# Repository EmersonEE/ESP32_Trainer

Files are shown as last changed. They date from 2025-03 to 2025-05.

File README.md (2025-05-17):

# ESP32 Trainer
Proyecto de Electrónica Aplicada 1 - **USAC**

 





 


# 📘 Temario del Proyecto

- 🔹 [Introducción](#-introducción)
- 🔹 [ESP32 Trainer](#-esp32-trainer)
- 🔹 [ESP32 Trainer Pinout](#esp32-trainer-pinout)
- 🔹 [Materiales](#-materiales)
- 🔹 [Diseño PCB - KiCad](#-diseño-pcb---kicad)
- 🔹 [Proyectos Demostrativos](#-proyectos-demostrativos)
<!-- - 🎥 [Video de Funcionamiento](#video-de-funcionamiento) -->

---

## 🧩 Introducción

En el ámbito del diseño electrónico y el desarrollo de prototipos, existe una necesidad creciente de contar con herramientas integradas que simplifiquen el proceso de aprendizaje, experimentación y construcción de soluciones funcionales. Las placas de desarrollo convencionales suelen requerir múltiples módulos adicionales para realizar proyectos completos, lo que incrementa la complejidad, los costos y el tiempo de implementación.

Este proyecto propone el diseño y fabricación de una **placa entrenadora basada en el [ESP32-WROOM-32](https://www.espressif.com/sites/default/files/documentation/esp32-wroom-32_datasheet_en.pdf)**, orientada a estudiantes, makers y profesionales. Su objetivo es integrar en una sola plataforma los elementos esenciales para trabajar con entradas/salidas digitales y analógicas, comunicación serial, control de cargas de alto voltaje, y más.

Entre sus características destacan:

- 🔘 Botones, LEDs y potenciómetros integrados para pruebas rápidas.
- ⚡ Control de cargas de 110V/220V mediante relés.
- 🔌 Interfaces UART, I2C y SPI disponibles desde headers.
- 📦 Diseño compacto y profesional en PCB de doble capa.

Con esta solución, se busca facilitar el desarrollo de proyectos de electrónica y automatización, reduciendo la necesidad de hardware adicional y mejorando la experiencia de aprendizaje.

[🔙 Volver al Temario](#-temario-del-proyecto)

## 🔌 ESP32 Trainer

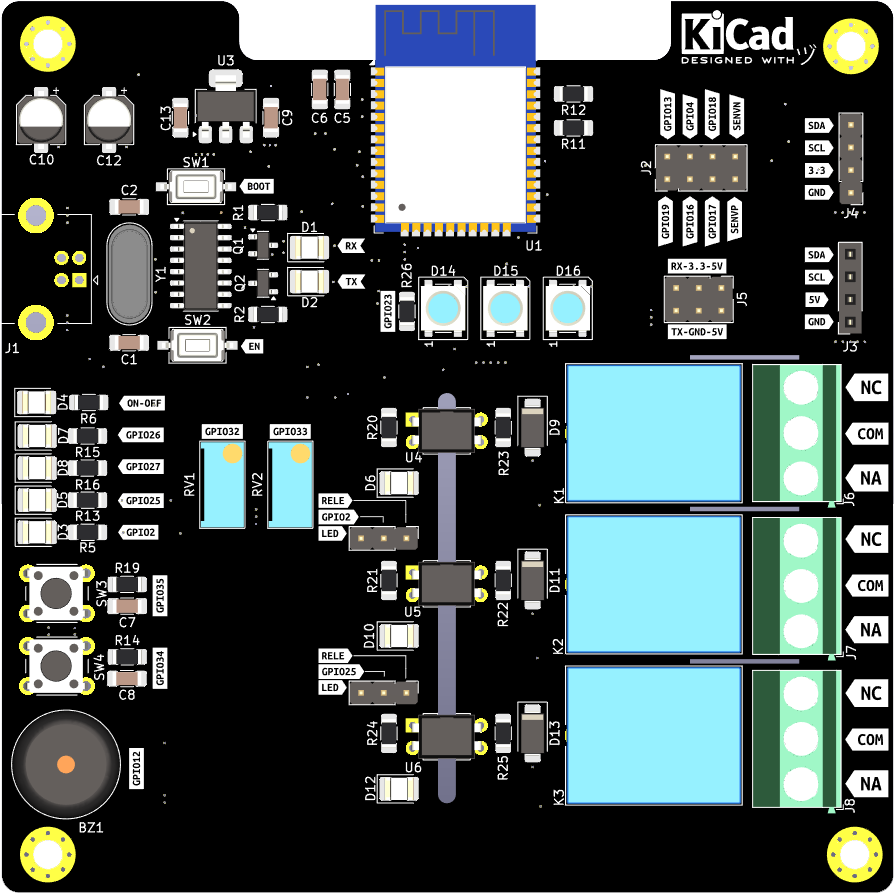
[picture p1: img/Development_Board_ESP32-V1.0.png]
ESP32 Trainer


[🔙 Volver al Temario](#-temario-del-proyecto)

## ESP32 Trainer Pinout

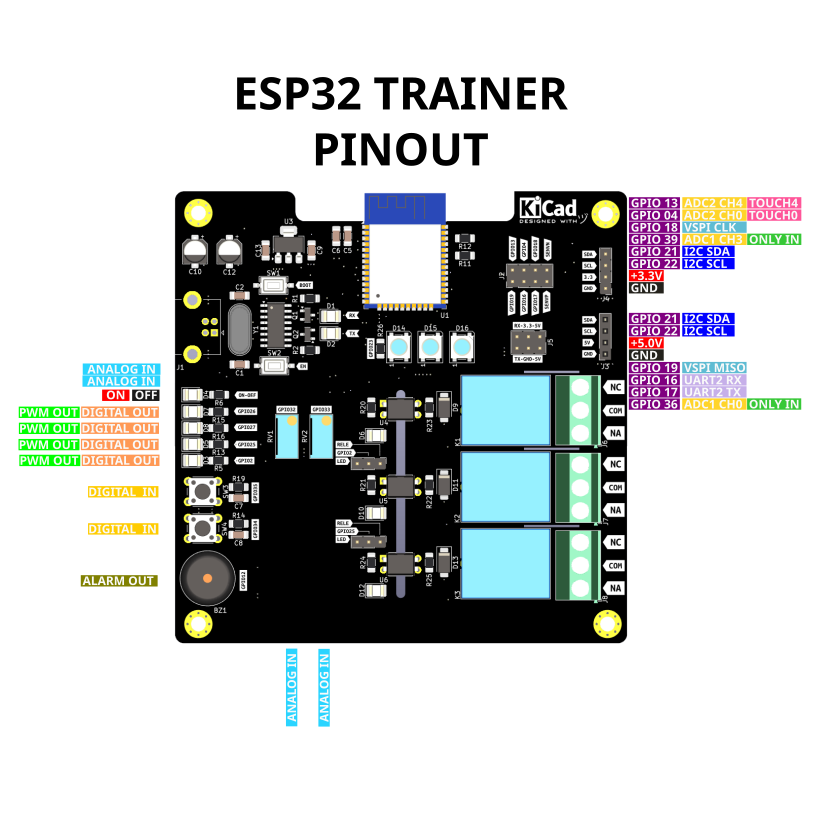
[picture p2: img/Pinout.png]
ESP32 Trainer Pinout


[Ver en PDF](pinout_esp32.pdf)

[🔙 Volver al Temario](#-temario-del-proyecto)

## 🧰 Materiales  

En esta sección se detallan todos los componentes electrónicos utilizados para el ensamblaje de la placa entrenadora basada en el ESP32-WROOM-32. La tabla incluye el identificador de cada componente, la cantidad necesaria, su valor o referencia, y el modelo de huella utilizado en el diseño PCB con KiCad.

<details><summary><b>Lista de Materiales  - BOM</b></summary>

| 🧾 Componente | 🔢 Cantidad | 💡 Valor | 📐 Huella (KiCad) |
|---|---|---|---|
| BZ1 | 1 | Buzzer | Buzzer_12x9.5RM7.6 |
| C1, C2 | 2 | 22pF | C_1206_3216Metric_Pad1.33x1.80mm_HandSolder |
| C10, C12 | 2 | 100uF | CP_Elec_5x5.4 |
| C11, C13, C5, C6, C9 | 5 | 100nF | C_1206_3216Metric_Pad1.33x1.80mm_HandSolder |
| C14–C16, C3–C4, C7–C8 | 7 | 0.1uF | C_1206_3216Metric_Pad1.33x1.80mm_HandSolder |
| D1, D10, D7  | 3 | LED Verde | LED_1210_3225Metric_Pad1.42x2.65mm_HandSolder |
| D11, D13, D9 | 3 | SS24 | D_SMA |
| D12, D3, D8  | 3 | LED Azul | LED_1210_3225Metric_Pad1.42x2.65mm_HandSolder |
| D14–D16 | 3 | WS2812B | LED_WS2812B_PLCC4_5.0x5.0mm_P3.2mm |
| D2 | 1 | LED Amarillo | LED_1210_3225Metric_Pad1.42x2.65mm_HandSolder |
| D4–D6 | 3 | LED Rojo | LED_1210_3225Metric_Pad1.42x2.65mm_HandSolder |
| J1 | 1 | USB B | USB_B_Lumberg_2411_02_Horizontal |
| J10, J9 | 2 | — | PinHeader_1x03_P2.54mm_Vertical |
| J2 | 1 | GPIO | PinHeader_2x04_P2.54mm_Vertical |
| J3 | 1 | OLED | PinSocket_1x04_P2.54mm_Vertical |
| J4 | 1 | — | PinHeader_1x04_P2.54mm_Vertical |
| J5 | 1 | — | PinHeader_2x03_P2.54mm_Vertical |
| J6–J8 | 3 | — | TerminalBlock_Phoenix_MKDS-1,5-3-5.08_1x03_P5.08mm_Horizontal |
| K1–K3 | 3 | — | Relay_SPDT_SANYOU_SRD_Series_Form_C |
| Q1–Q6 | 6 | MMBT3904 | SOT-23 |
| R1, R2, R7, R9, R11, R12 | 6 | 10K | R_1206_3216Metric_Pad1.30x1.75mm_HandSolder |
| R8, R10, R13–R16, R19–R21, R24 | 10 | 470 | R_1206_3216Metric_Pad1.30x1.75mm_HandSolder |
| R17, R22–R23, R25 | 4 | 2.2K | R_1206_3216Metric_Pad1.30x1.75mm_HandSolder |
| R18 | 1 | 4.7K | R_1206_3216Metric_Pad1.30x1.75mm_HandSolder |
| R26 | 1 | 220 | R_1206_3216Metric_Pad1.30x1.75mm_HandSolder |
| R3, R4 | 2 | 2K | R_1206_3216Metric_Pad1.30x1.75mm_HandSolder |
| R5, R6 | 2 | 1K | R_1206_3216Metric_Pad1.30x1.75mm_HandSolder |
| RV1, RV2 | 2 | 100K Pot | Potentiometer_Bourns_3296W_Vertical |
| SW1, SW2 | 2 | — | SW_Tactile_SPST_NO_Straight_CK_PTS636Sx25SMTRLFS |
| SW3, SW4 | 2 | — | SW_PUSH_6mm |
| U1 | 1 | ESP32-WROOM-32 | ESP32-WROOM-32 |
| U2 | 1 | CH340G | SOIC-16_3.9x9.9mm_P1.27mm |
| U3 | 1 | AMS1117-3.3 | SOT-223-3_TabPin2 |
| U4–U6 | 3 | PC817 | DIP-4_W7.62mm |
| Y1 | 1 | 12MHz | Crystal_HC49-4H_Vertical |
</details>

[🔙 Volver al Temario](#-temario-del-proyecto)

## 🖨️ Diseño PCB - KiCad

 [KiCad](https://www.kicad.org/) se utilizó para el diseño de la placa entrenadora basada en el ESP32-WROOM-32, permitiendo crear el esquemático del circuito, asignar huellas adecuadas a los componentes y generar el diseño del PCB en múltiples capas. Gracias a sus herramientas de visualización y comprobación de reglas, fue posible optimizar el diseño para su posterior fabricación con alta precisión.

<details><summary><b>📏 Esquemático KiCad</b></summary>

Esquemático diseñado en Kicad, se puede visualizar de forma completa en este enlace [Esquemático](Schematic.pdf)
<div align="center" >
  <p style="text-align:center;"><strong>Power Supply</strong></p>
  <p style="text-align:center;">
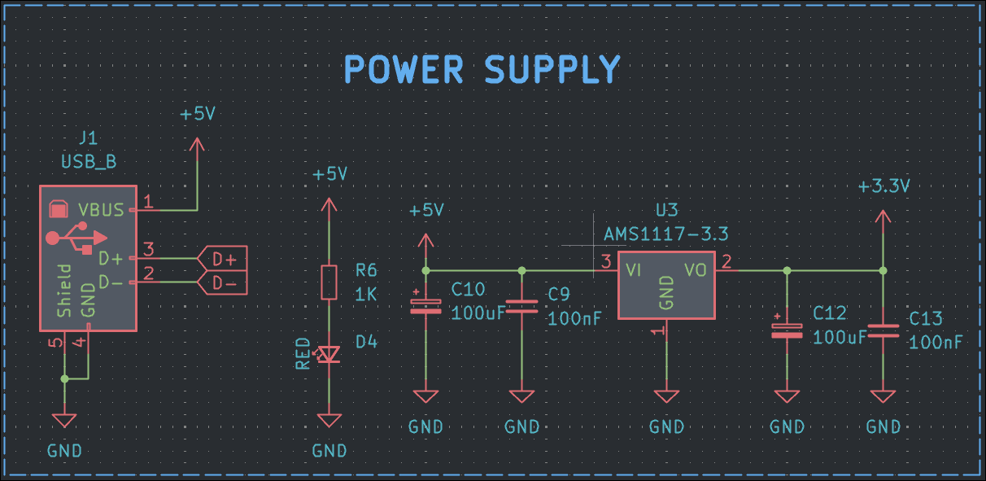
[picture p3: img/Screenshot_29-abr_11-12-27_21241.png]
Power Supply
    
  </p>
</div>

<div align="center" >
  <p style="text-align:center;"><strong>USB To TTL</strong></p>
  <p style="text-align:center;">
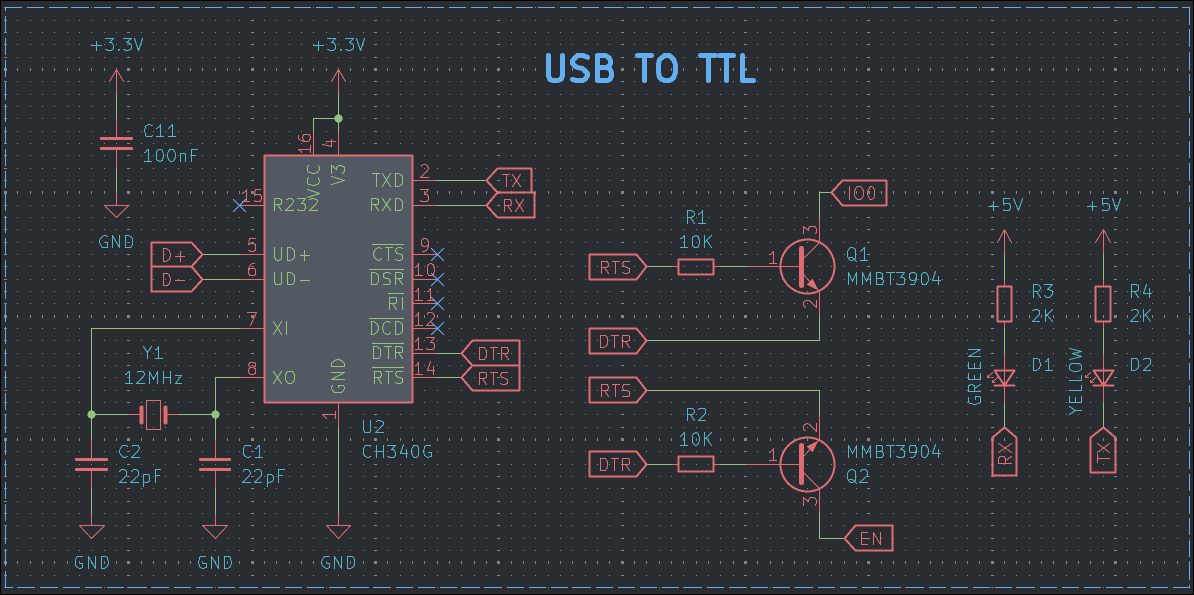
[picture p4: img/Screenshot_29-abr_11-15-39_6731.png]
USB To TTL
    
  </p>
</div>

<div align="center" >
  <p style="text-align:center;"><strong>Boot Settings</strong></p>
  <p style="text-align:center;">
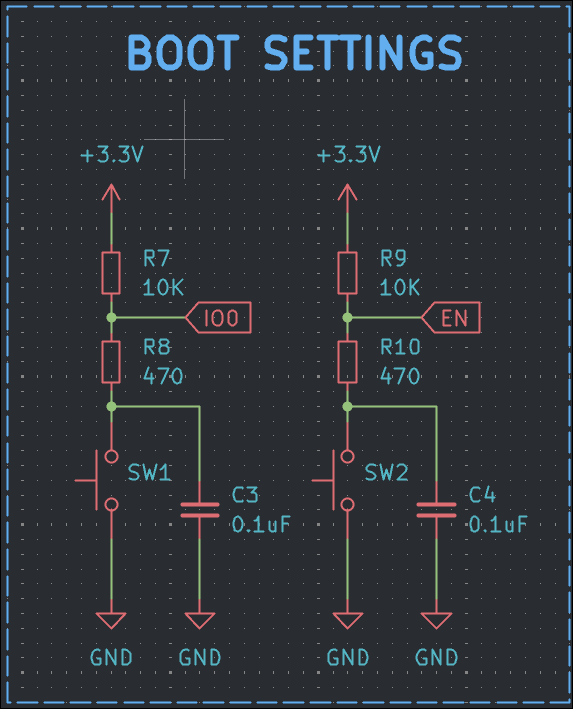
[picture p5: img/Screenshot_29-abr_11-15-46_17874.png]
Boot Settings
    
  </p>
</div>

<div align="center" >
  <p style="text-align:center;"><strong>INPUT - OUTPUT Digital</strong></p>
  <p style="text-align:center;">
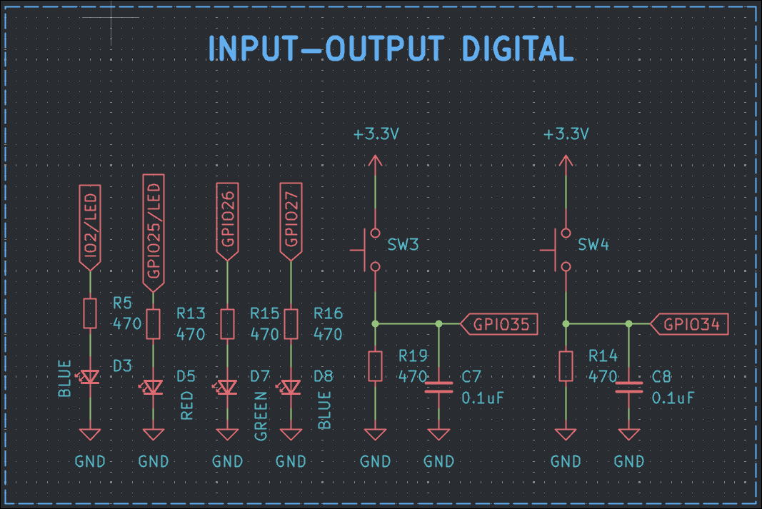
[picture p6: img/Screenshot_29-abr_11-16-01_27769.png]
INPUT - OUTPUT Digital
    
  </p>
</div>

<div align="center" >
  <p style="text-align:center;"><strong>ESP32-WROOM</strong></p>
  <p style="text-align:center;">
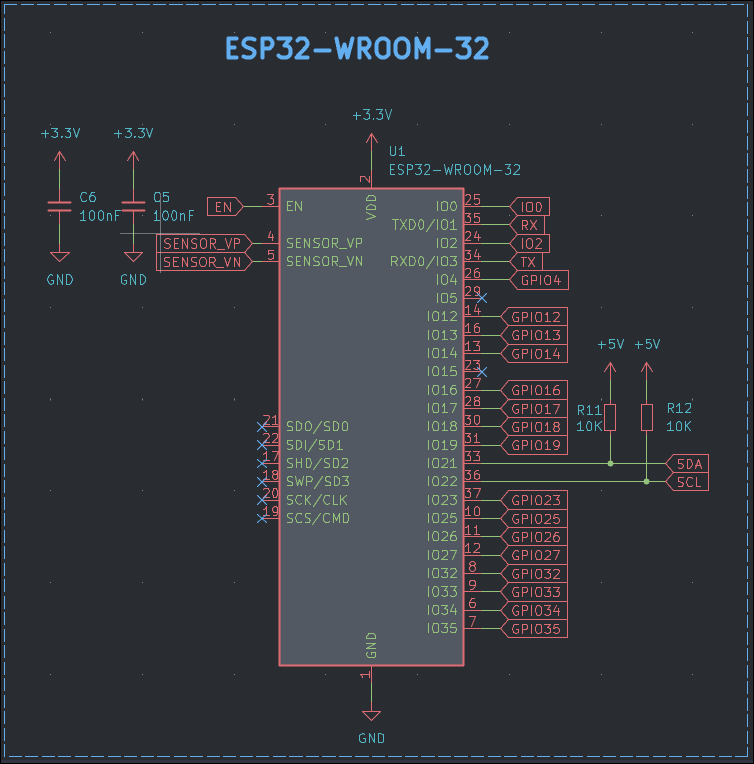
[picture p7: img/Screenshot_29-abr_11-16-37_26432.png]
ESP32-WROOM
    
  </p>
</div>

<div align="center" >
  <p style="text-align:center;"><strong>Analog INPUT</strong></p>
  <p style="text-align:center;">
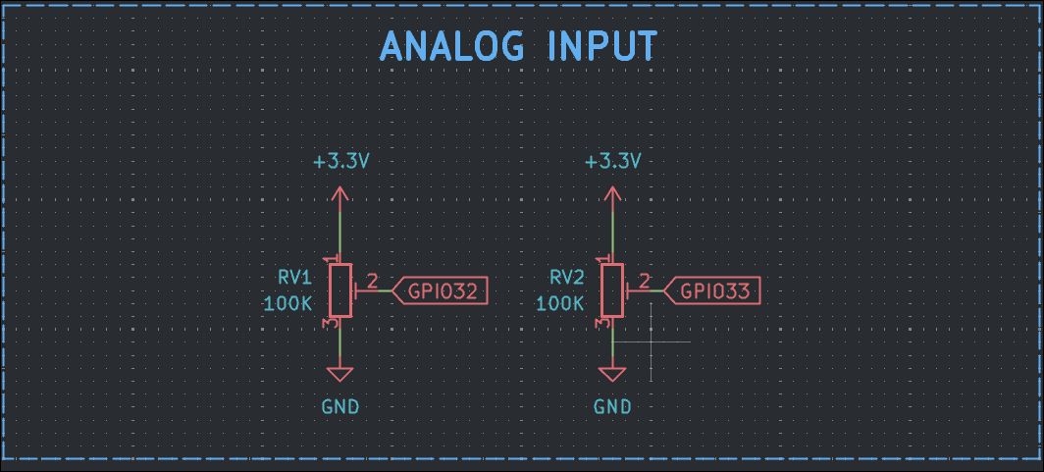
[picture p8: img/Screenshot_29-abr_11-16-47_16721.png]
Analog INPUT
    
  </p>
</div>

<div align="center" >
  <p style="text-align:center;"><strong>LED WS2812B</strong></p>
  <p style="text-align:center;">
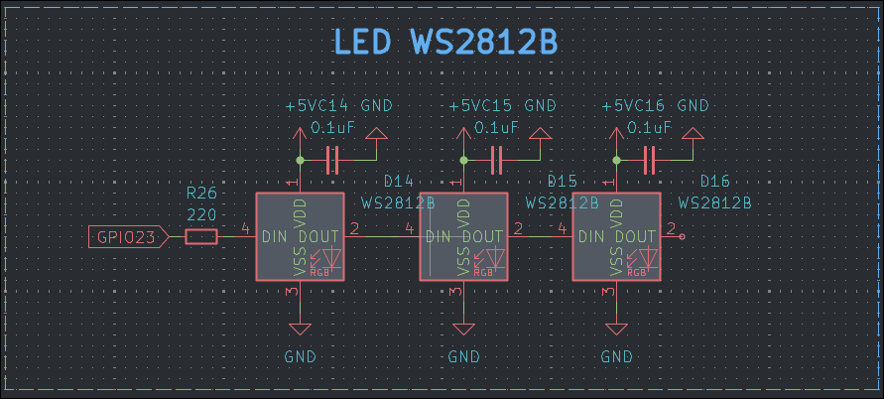
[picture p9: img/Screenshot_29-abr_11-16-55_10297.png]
LED WS2812B
    
  </p>
</div>

<div align="center" >
  <p style="text-align:center;"><strong>Buzzer</strong></p>
  <p style="text-align:center;">
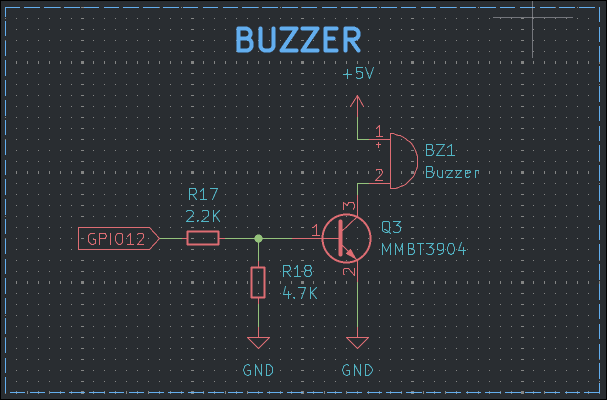
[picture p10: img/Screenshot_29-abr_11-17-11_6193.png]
Buzzer
    
  </p>
</div>

<div align="center" >
  <p style="text-align:center;"><strong>Jumper Selector</strong></p>
  <p style="text-align:center;">
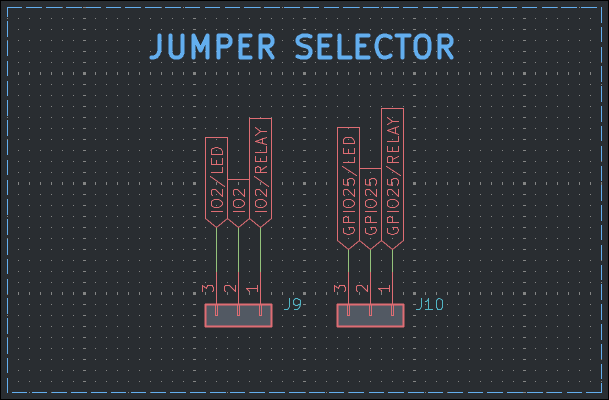
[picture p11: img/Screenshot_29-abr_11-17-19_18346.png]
Jumper Selector
    
  </p>
</div>

<div align="center" >
  <p style="text-align:center;"><strong>GPIO - UART</strong></p>
  <p style="text-align:center;">
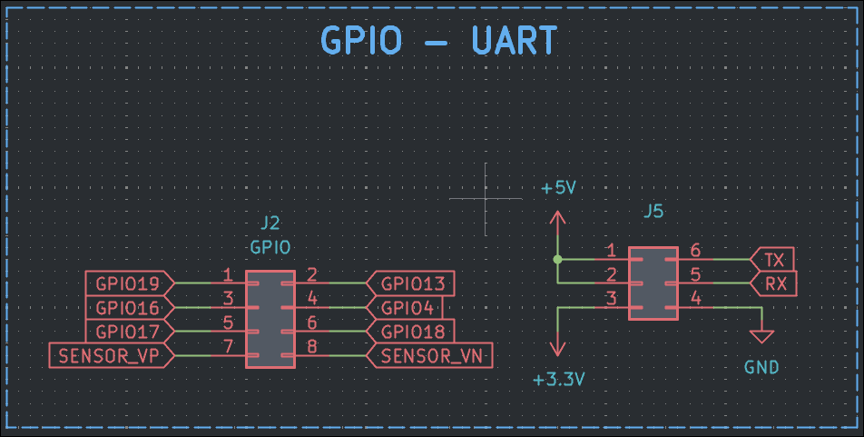
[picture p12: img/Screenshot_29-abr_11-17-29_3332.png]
GPIO - UART
    
  </p>
</div>

<div align="center" >
  <p style="text-align:center;"><strong>OLED I2C</strong></p>
  <p style="text-align:center;">
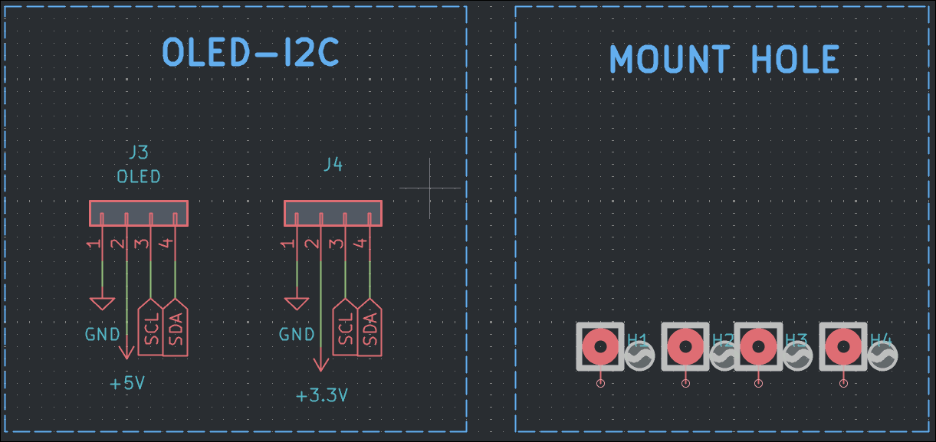
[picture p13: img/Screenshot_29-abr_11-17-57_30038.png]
    
  </p>
</div>

<div align="center" >
  <p style="text-align:center;"><strong>Rele</strong></p>
  <p style="text-align:center;">
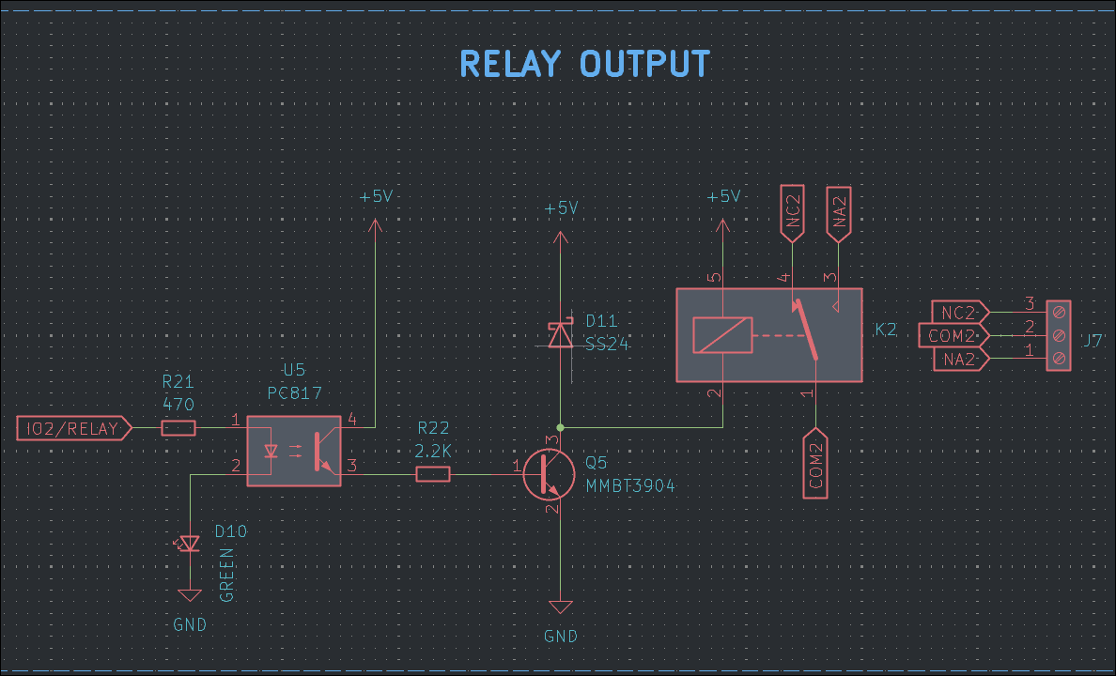
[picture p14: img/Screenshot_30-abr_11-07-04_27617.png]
    
  </p>
</div>

</details>

<details><summary><b>🔌 Diseño del PCB </b></summary>

Diseño de la PCB en dos caras, se puede descargar los archivos para su modificación o su estudio en aca [Descargar archivos del  PCB](https://github.com/EmersonEE/ESP32_Trainer/releases/tag/untagged-a26e2b24809520548798)

<div align="center" >
  <p style="text-align:center;"><strong>Diseño 3D</strong></p>
  <p style="text-align:center;">
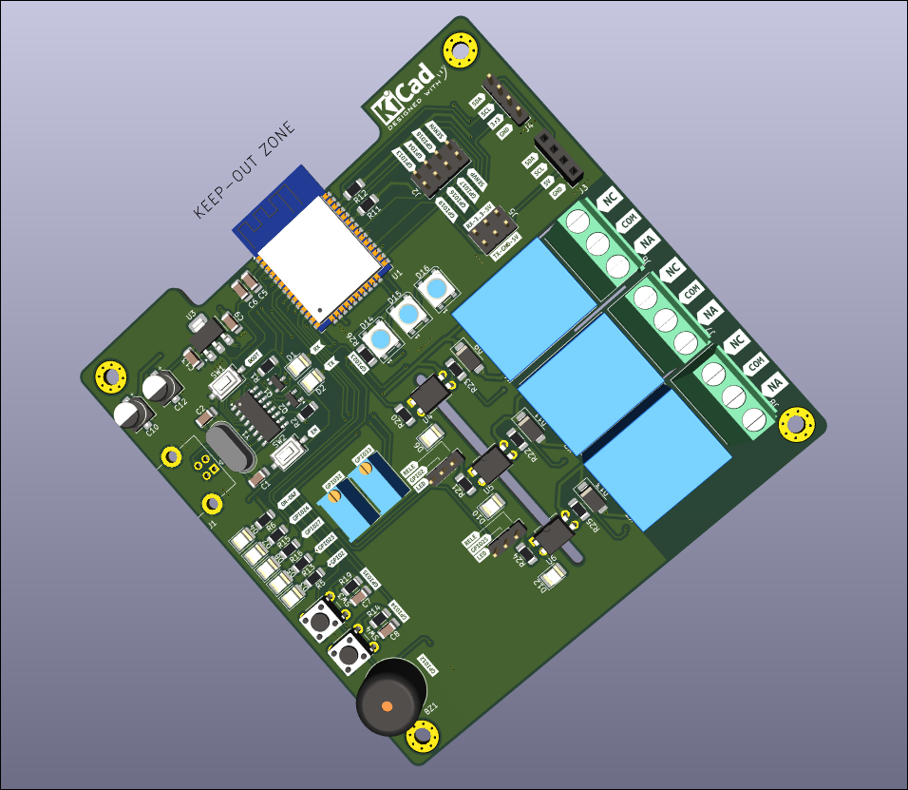
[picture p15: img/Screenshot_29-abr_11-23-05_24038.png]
    
  </p>
</div>

<div align="center" >
  <p style="text-align:center;"><strong>Capa BUTTON</strong></p>
  <p style="text-align:center;">
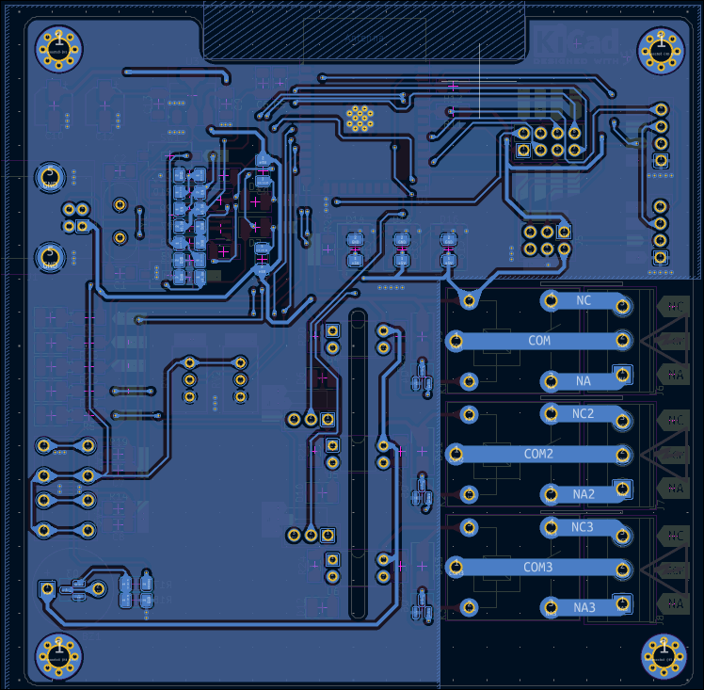
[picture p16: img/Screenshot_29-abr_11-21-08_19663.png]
    
  </p>
</div>

<div align="center" >
  <p style="text-align:center;"><strong>Capa TOP</strong></p>
  <p style="text-align:center;">
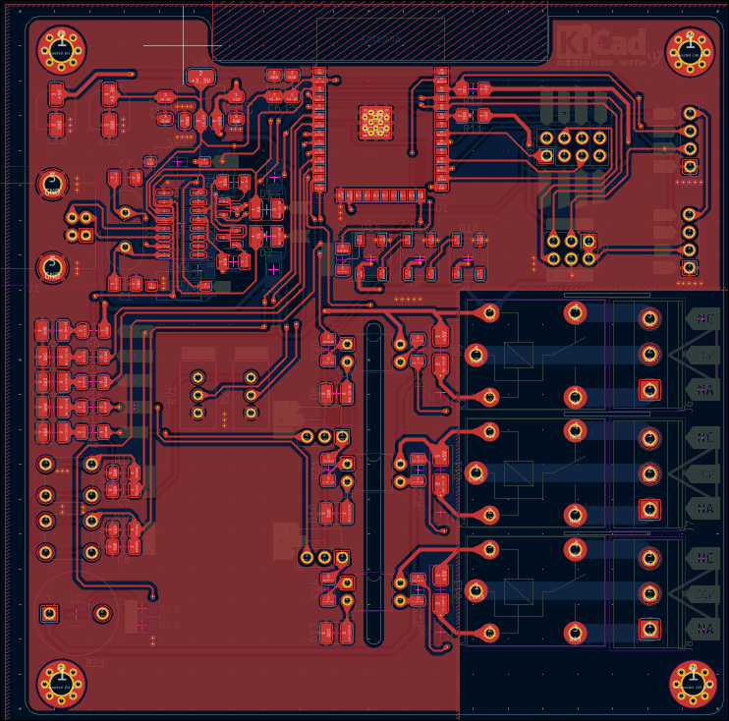
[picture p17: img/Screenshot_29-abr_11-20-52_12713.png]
    
  </p>
</div>

<div align="center" >
  <p style="text-align:center;"><strong>Serigrafía</strong></p>
  <p style="text-align:center;">
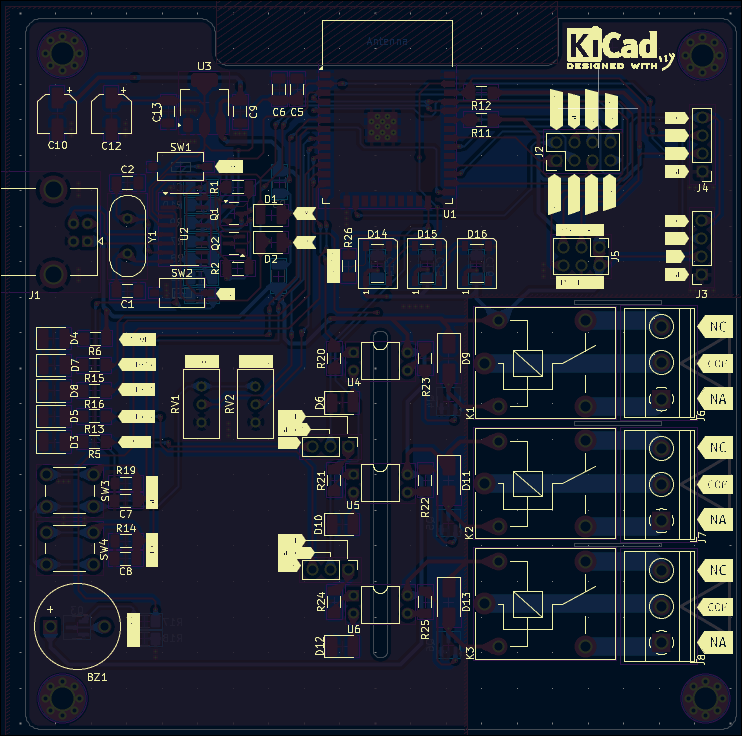
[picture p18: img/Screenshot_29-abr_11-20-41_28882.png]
    
  </p>
</div>

</details>

<details><summary><b>🖥️ Introducción a KiCad</b></summary>

KiCad es una suite de software libre para el diseño de circuitos electrónicos y la creación de placas de circuito impreso (PCB). Desarrollado originalmente por Jean-Pierre Charras y mantenido actualmente por la comunidad y la Fundación KiCad, es una herramienta poderosa y versátil que compite con soluciones comerciales en la industria electrónica.

[KiCad](https://www.kicad.org/) permite a los diseñadores electrónicos trabajar de forma integral en todo el flujo de desarrollo de hardware, desde la creación de esquemáticos eléctricos hasta la generación de archivos Gerber listos para fabricación. Entre sus principales características destacan:

✏️ Editor de esquemáticos intuitivo, con bibliotecas extensas de componentes.

🧩 Gestor de huellas (footprints) que vincula componentes con sus representaciones físicas en el PCB.

🖨️ Editor de PCB con reglas de diseño personalizables y soporte para múltiples capas.

📷 Visualizador 3D para inspeccionar el diseño de la placa antes de fabricarla.

🔁 Integración con herramientas externas para simulación eléctrica (SPICE) o gestión de proyectos.

Al ser de código abierto y multiplataforma (disponible en Windows, Linux y macOS), KiCad es una opción ideal tanto para estudiantes, makers, como para profesionales del diseño electrónico.

## 📺 Tutoriales KiCad

### Guía para el uso de KiCad #1

Guía para el uso de KiCad #1 (https://www.youtube.com/watch?v=3N2reU-T1Rk&list=PLkyFkq6L7y6vNRUAsLx8TKmJbIyapzemn)

### Guía para el uso de KiCad #2

Guía para el uso de KiCad #2 (https://youtu.be/d3H3tfU4zBI)

### Guía para el uso de KiCad #3

Guía para el uso de KiCad #3 (https://youtu.be/7YaQ3QVPdN0)

</details>

[🔙 Volver al Temario](#-temario-del-proyecto)

## 🧪 Proyectos Demostrativos

Con el objetivo de validar y demostrar la versatilidad de la placa entrenadora basada en el ESP32-WROOM-32, se desarrollaron cinco proyectos demostrativos que abarcan desde aplicaciones básicas hasta implementaciones más avanzadas. Estos proyectos fueron diseñados para cubrir distintos niveles de complejidad, permitiendo así ilustrar de manera progresiva el potencial de la placa tanto en el ámbito educativo como en entornos de prototipado profesional.

Cada proyecto está enfocado en destacar una o varias funcionalidades integradas de la placa, como el uso de salidas digitales con visualización por LEDs, entradas analógicas controladas por potenciómetros, manejo de salidas de alto voltaje mediante relés, así como el uso de interfaces de comunicación como UART, I2C.

<details><summary><b>🤖 💡 Proyecto 1 </b></summary>

## Proyecto: Control de Intensidad de LED con Clases Personalizadas

Este proyecto implementa un sistema modular en Arduino para el **control de un LED** utilizando clases personalizadas en C++.

### Características principales:

- **Clase `LED`**: Permite controlar un LED conectado a un pin digital o PWM. Soporta funciones como encendido, apagado, parpadeo y control de brillo mediante modulación por ancho de pulso (PWM).
- **Clase `PWM`**: Facilita la lectura de entradas analógicas y entrega los valores en diferentes formatos: raw, mapeado (0-255) y en voltios.
- En la función `setup()`, se configura un LED en el pin 2 en modo PWM.
- En el `loop()`, la intensidad del LED se ajusta dinámicamente según la lectura analógica del pin 32.

Este proyecto demuestra cómo estructurar el código de forma reutilizable y orientada a objetos para controlar hardware de forma más eficiente.

🔗 [Ver código del Proyecto 1](/Codigos%20Proyectos/Proyecto_1/)

</details>

<details><summary><b>🤖 💡 Proyecto 2 </b></summary>

## Proyecto: Detección de Movimiento y Control Remoto vía Telegram

Este proyecto implementa un sistema de monitoreo basado en **ESP32** que permite detectar movimiento mediante un sensor **PIR** y enviar notificaciones en tiempo real a un usuario específico a través de un bot de **Telegram**.

### Características principales:

- **Detección de movimiento**: El sensor PIR detecta presencia o movimiento en el entorno.
- **Notificación instantánea**: Cuando se detecta movimiento, el ESP32 envía un mensaje automáticamente al usuario mediante Telegram.
- **Control remoto**: El usuario puede encender o apagar un **LED** conectado al ESP32 enviando comandos personalizados al bot.
- **Interacción segura y directa**: Solo el usuario autorizado puede comunicarse con el bot para recibir alertas o enviar comandos.
- **Aplicación práctica**: Ideal para sistemas de vigilancia, alarmas domésticas o control remoto básico mediante mensajería.

🔗 [Ver código del Proyecto 2](/Codigos%20Proyectos/Proyecto_2/)

</details>

<details><summary><b>🤖 💡 Proyecto 3 </b></summary>

## Proyecto: Control de Focos con ESP32 y ESP RainMaker

Este proyecto utiliza un ESP32 para controlar tres focos a través de la plataforma **ESP RainMaker**, permitiendo el encendido y apagado mediante comandos de voz e integración con asistentes virtuales.

### Características principales:

- **Control inteligente**: Tres relés controlan los focos conectados a los pines **25**, **2** y **14**.
- **Dispositivos virtuales**: Se crean tres dispositivos en la nube:
  - `Foco Sala`
  - `Foco Comedor`
  - `Foco Cuarto`
- **Comandos de voz**: Compatible con asistentes virtuales mediante ESP RainMaker.
- **Aprovisionamiento BLE**: Permite la configuración inicial de red Wi-Fi mediante Bluetooth.
- **Callback personalizado**: Al recibir una orden desde RainMaker, el estado del relé correspondiente se actualiza.
- **Actualización OTA**: Soporte para actualizaciones de firmware a distancia.
- **Servicios integrados**:
  - Zona horaria
  - Programación de tareas
- **Indicadores y botones**:
  - LED indica conexión Wi-Fi activa.
  - Botón en el pin **0** permite:
    - Restablecer Wi-Fi (pulsación breve)
    - Restablecer de fábrica (pulsación prolongada)

Este proyecto es ideal para aplicaciones de automatización del hogar, demostrando la capacidad de la placa para integrarse con servicios en la nube y control por voz.

🔗 [Ver código del Proyecto 3](/Codigos%20Proyectos/Proyecto_3/)

</details>

<details><summary><b>🤖 💡 Proyecto 4 </b></summary>

## Proyecto: Controlador Web para LED RGB con ESP32

Gracias al módulo WiFi integrado del **ESP32**, es posible crear un controlador web altamente funcional para un **LED RGB**, eliminando la necesidad de ingresar manualmente valores RGB cada vez que se desea cambiar el color.

En lugar de eso, este proyecto propone una **interfaz web atractiva e interactiva**, que permite seleccionar colores de forma visual e intuitiva. Para ello, se utiliza la biblioteca **iro.js**, un potente selector de color en JavaScript que ofrece una experiencia de usuario dinámica y visualmente agradable.

La comunicación entre la interfaz web y el ESP32 se realiza mediante **WebSockets**, lo que permite actualizar el color en tiempo real sin necesidad de recargar la página. El **ESP32 actúa como servidor Web**, sirviendo la interfaz HTML y gestionando el servidor WebSocket para recibir los datos del color seleccionado.

Este enfoque proporciona un sistema eficiente, moderno y fácil de usar para controlar luces RGB a través de cualquier dispositivo con acceso a un navegador web.

[Manera de subir la carpeta Data al ESP32](https://randomnerdtutorials.com/esp32-vs-code-platformio-spiffs/)

🔗 [Ver código del Proyecto 4](/Codigos%20Proyectos/Proyecto_4/)

</details>

<details><summary><b>🤖 💡 Proyecto 5 </b></summary>

## Proyecto: Alerta de Proximidad con Sensor Ultrasónico, Pantalla OLED y Buzzer

Este proyecto utiliza un **sensor ultrasónico**, una **pantalla OLED SSD1306** y un **buzzer** para crear un sistema de alerta de proximidad.

### Funcionamiento:

- El **sensor ultrasónico** mide constantemente la distancia a un objeto frente a él.
- La **pantalla OLED** muestra en tiempo real la distancia detectada en centímetros.
- Cuando un objeto se acerca a una **distancia mínima predefinida**, el **buzzer** se activa como señal de advertencia sonora.
- Si el objeto se aleja nuevamente más allá del umbral, el buzzer se desactiva automáticamente.

Este sistema es útil como sistema de asistencia para estacionamiento, detección de intrusos, monitoreo de espacios reducidos, entre otros usos prácticos que requieren una alerta ante la cercanía de objetos.

🔗 [Ver código del Proyecto 5](/Codigos%20Proyectos/Proyecto_5/)

</details>

[🔙 Volver al Temario](#-temario-del-proyecto)

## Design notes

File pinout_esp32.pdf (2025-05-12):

ANALOG IN

ANALOG IN

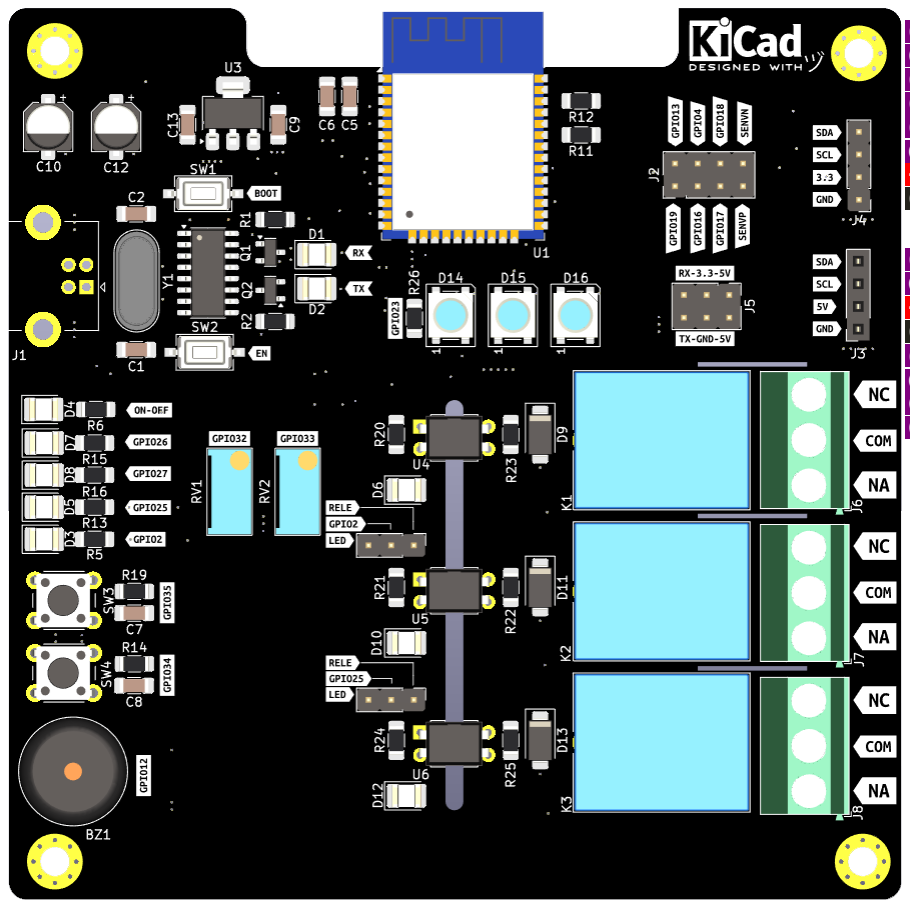
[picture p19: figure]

ANALOG IN
ANALOG IN

PWM OUT DIGITAL OUT
PWM OUT DIGITAL OUT

ON OFF

PWM OUT DIGITAL OUT
PWM OUT DIGITAL OUT

DIGITAL IN

DIGITAL IN

ALARM OUT

GPIO 13 | ADC2 CH4 | TOUCH4
GPIO 04 | ADC2 CH0 | TOUCH0
GPIO 18 | VSPI CLK
GPIO 39 | ADC1 CH3 | ONLY IN
GPIO 21 | I2C SDA
GPIO 22 | I2C SCL

GPIO 19
GPIO 16
GPIO 17

VSPI MISO
UART2 RX
UART2 TX
GPIO 36 | ADC1 CH0 | ONLY IN

+3.3V
GND
GPIO 21 | I2C SDA
GPIO 22 | I2C SCL
+5.0V
GND

# ESP32 TRAINER PINOUT

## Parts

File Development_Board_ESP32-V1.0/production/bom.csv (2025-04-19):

Designator | Footprint | Quantity | Value | LCSC Part #
BZ1 | Buzzer_12x9.5RM7.6 | 1 | Buzzer
C1, C2 | 1206 | 2 | 22pF
C10, C12 | CP_Elec_5x5.4 | 2 | 100uF
C11, C13, C5, C6, C9 | 1206 | 5 | 100nF
C14, C15, C16, C3, C4, C7, C8 | 1206 | 7 | 0.1uF
D1, D10, D7 | 1210 | 3 | GREEN
D11, D13, D9 | D_SMA | 3 | SS24
D12, D3, D8 | 1210 | 3 | BLUE
D14, D15, D16 | LED_WS2812B_PLCC4_5.0x5.0mm_P3.2mm | 3 | WS2812B
D2 | 1210 | 1 | YELLOW
D4, D5, D6 | 1210 | 3 | RED
J1 | USB_B_Lumberg_2411_02_Horizontal | 1 | USB_B
J10, J9 | PinHeader_1x03_P2.54mm_Vertical | 2 | ~
J2 | PinHeader_2x04_P2.54mm_Vertical | 1 | GPIO
J3 | PinSocket_1x04_P2.54mm_Vertical | 1 | OLED
J4 | PinHeader_1x04_P2.54mm_Vertical | 1 | ~
J5 | PinHeader_2x03_P2.54mm_Vertical | 1 | ~
J6, J7, J8 | TerminalBlock_Phoenix_MKDS-1,5-3-5.08_1x03_P5.08mm_Horizontal | 3 | ~
K1, K2, K3 | Relay_SPDT_SANYOU_SRD_Series_Form_C | 3 | ~
Q1, Q2, Q3, Q4, Q5, Q6 | SOT-23 | 6 | MMBT3904
R1, R11, R12, R2, R7, R9 | 1206 | 6 | 10K
R10, R13, R14, R15, R16, R19, R20, R21, R24, R5, R8 | 1206 | 11 | 470
R17, R22, R23, R25 | 1206 | 4 | 2.2K
R18 | 1206 | 1 | 4.7K
R26 | 1206 | 1 | 220
R3, R4 | 1206 | 2 | 2K
R6 | 1206 | 1 | 1K
RV1, RV2 | Potentiometer_Bourns_3296W_Vertical | 2 | 100K
SW1, SW2 | SW_Tactile_SPST_NO_Straight_CK_PTS636Sx25SMTRLFS | 2 | ~
SW3, SW4 | SW_PUSH_6mm | 2 | ~
U1 | ESP32-WROOM-32 | 1 | ESP32-WROOM-32
U2 | SOIC-16_3.9x9.9mm_P1.27mm | 1 | CH340G
U3 | SOT-223-3_TabPin2 | 1 | AMS1117-3.3
U4, U5, U6 | DIP-4_W7.62mm | 3 | PC817
Y1 | Crystal_HC49-4H_Vertical | 1 | 12MHz

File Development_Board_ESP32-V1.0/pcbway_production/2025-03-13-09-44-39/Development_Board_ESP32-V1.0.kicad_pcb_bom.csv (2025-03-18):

Designator | Quantity | Value | Footprint | Package | MPN | DNP | Mount_Type | Description
BZ1 | 1 | Buzzer | Buzzer_12x9.5RM7.6 |  |  |  | tht | Buzzer, polarized
C1, C2 | 2 | 22pF | C_1206_3216Metric_Pad1.33x1.80mm_HandSolder |  |  |  | smt | Unpolarized capacitor, small symbol
C10, C12 | 2 | 100uF | CP_Elec_5x5.4 |  |  |  | smt | Polarized capacitor, small symbol
C11, C13, C5, C6, C9 | 5 | 100nF | C_1206_3216Metric_Pad1.33x1.80mm_HandSolder |  |  |  | smt | Unpolarized capacitor, small symbol
C14, C15, C16, C3, C4, C7, C8 | 7 | 0.1uF | C_1206_3216Metric_Pad1.33x1.80mm_HandSolder |  |  |  | smt | Unpolarized capacitor, small symbol
D1, D10, D7 | 3 | GREEN | LED_1210_3225Metric_Pad1.42x2.65mm_HandSolder |  |  |  | smt | Light emitting diode, small symbol
D11, D13, D9 | 3 | SS24 | D_SMA |  |  |  | smt | 40V 2A Schottky Diode, SMA
D12, D3, D8 | 3 | BLUE | LED_1210_3225Metric_Pad1.42x2.65mm_HandSolder |  |  |  | smt | Light emitting diode, small symbol
D14, D15, D16 | 3 | WS2812B | LED_WS2812B_PLCC4_5.0x5.0mm_P3.2mm |  |  |  | smt | RGB LED with integrated controller
D2 | 1 | YELLOW | LED_1210_3225Metric_Pad1.42x2.65mm_HandSolder |  |  |  | smt | Light emitting diode, small symbol
D4, D5, D6 | 3 | RED | LED_1210_3225Metric_Pad1.42x2.65mm_HandSolder |  |  |  | smt | Light emitting diode, small symbol
J1 | 1 | USB_B | USB_B_Lumberg_2411_02_Horizontal |  |  |  | tht | USB Type B connector
J10, J9 | 2 | ~ | PinHeader_1x03_P2.54mm_Vertical |  |  |  | tht | Generic connector, single row, 01x03, script generated (kicad-library-utils/schlib/autogen/connector/)
J2 | 1 | GPIO | PinHeader_2x04_P2.54mm_Vertical |  |  |  | tht | Generic connector, double row, 02x04, odd/even pin numbering scheme (row 1 odd numbers, row 2 even numbers), script generated (kicad-library-utils/schlib/autogen/connector/)
J3 | 1 | OLED | PinSocket_1x04_P2.54mm_Vertical |  |  |  | tht | Generic connector, single row, 01x04, script generated (kicad-library-utils/schlib/autogen/connector/)
J4 | 1 | ~ | PinHeader_1x04_P2.54mm_Vertical |  |  |  | tht | Generic connector, single row, 01x04, script generated (kicad-library-utils/schlib/autogen/connector/)
J5 | 1 | ~ | PinHeader_2x03_P2.54mm_Vertical |  |  |  | tht | Generic connector, double row, 02x03, counter clockwise pin numbering scheme (similar to DIP package numbering), script generated (kicad-library-utils/schlib/autogen/connector/)
J6, J7, J8 | 3 | ~ | TerminalBlock_Phoenix_MKDS-1,5-3-5.08_1x03_P5.08mm_Horizontal |  |  |  | tht | Generic screw terminal, single row, 01x03, script generated (kicad-library-utils/schlib/autogen/connector/)
K1, K2, K3 | 3 | ~ | Relay_SPDT_SANYOU_SRD_Series_Form_C |  |  |  | tht | Sanyo SRD relay, Single Pole Miniature Power Relay,
Q1, Q2, Q3, Q4, Q5, Q6 | 6 | MMBT3904 | SOT-23 |  |  |  | smt | 0.2A Ic, 40V Vce, Small Signal NPN Transistor, SOT-23
R1, R11, R12, R2, R7, R9 | 6 | 10K | R_1206_3216Metric_Pad1.30x1.75mm_HandSolder |  |  |  | smt | Resistor, small symbol
R10, R13, R14, R15, R16, R19, R20, R21, R24, R8 | 10 | 470 | R_1206_3216Metric_Pad1.30x1.75mm_HandSolder |  |  |  | smt | Resistor, small symbol
R17, R22, R23, R25 | 4 | 2.2K | R_1206_3216Metric_Pad1.30x1.75mm_HandSolder |  |  |  | smt | Resistor, small symbol
R18 | 1 | 4.7K | R_1206_3216Metric_Pad1.30x1.75mm_HandSolder |  |  |  | smt | Resistor, small symbol
R26 | 1 | 220 | R_1206_3216Metric_Pad1.30x1.75mm_HandSolder |  |  |  | smt | Resistor, small symbol
R3, R4 | 2 | 2K | R_1206_3216Metric_Pad1.30x1.75mm_HandSolder |  |  |  | smt | Resistor, small symbol
R5, R6 | 2 | 1K | R_1206_3216Metric_Pad1.30x1.75mm_HandSolder |  |  |  | smt | Resistor, small symbol
RV1, RV2 | 2 | 100K | Potentiometer_Bourns_3296W_Vertical |  |  |  | tht | Trim-potentiometer
SW1, SW2 | 2 | ~ | SW_Tactile_SPST_NO_Straight_CK_PTS636Sx25SMTRLFS |  |  |  | smt | Push button switch, generic, two pins
SW3, SW4 | 2 | ~ | SW_PUSH_6mm |  |  |  | tht | Push button switch, generic, two pins
U1 | 1 | ESP32-WROOM-32 | ESP32-WROOM-32 |  |  |  | smt | RF Module, ESP32-D0WDQ6 SoC, Wi-Fi 802.11b/g/n, Bluetooth, BLE, 32-bit, 2.7-3.6V, onboard antenna, SMD
U2 | 1 | CH340G | SOIC-16_3.9x9.9mm_P1.27mm |  |  |  | smt | USB serial converter, UART, SOIC-16
U3 | 1 | AMS1117-3.3 | SOT-223-3_TabPin2 |  |  |  | smt | 1A Low Dropout regulator, positive, 3.3V fixed output, SOT-223
U4, U5, U6 | 3 | PC817 | DIP-4_W7.62mm |  |  |  | tht | DC Optocoupler, Vce 35V, CTR 50-300%, DIP-4
Y1 | 1 | 12MHz | Crystal_HC49-4H_Vertical |  |  |  | tht | Two pin crystal, small symbol

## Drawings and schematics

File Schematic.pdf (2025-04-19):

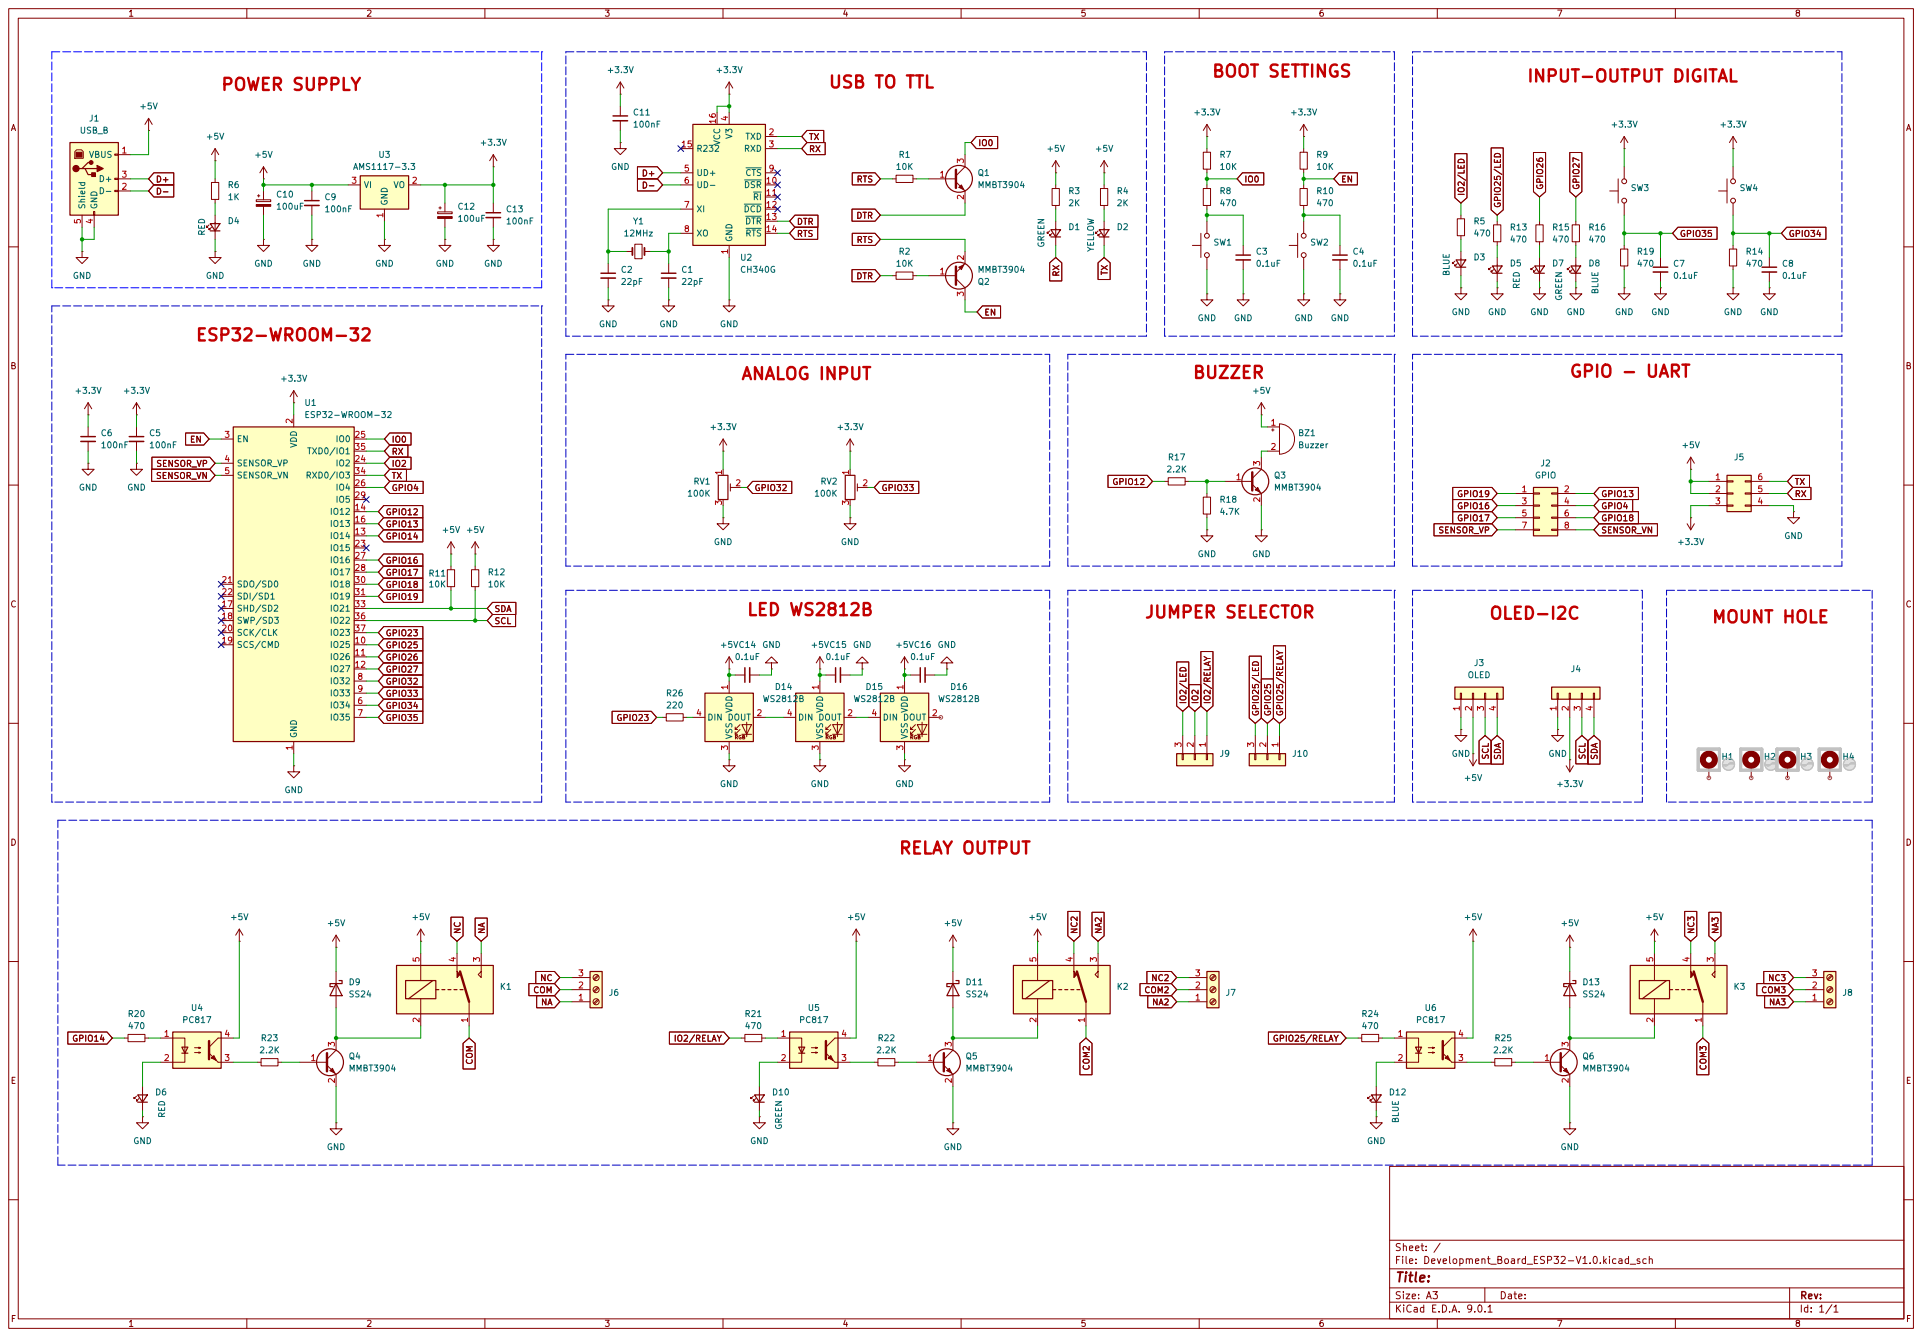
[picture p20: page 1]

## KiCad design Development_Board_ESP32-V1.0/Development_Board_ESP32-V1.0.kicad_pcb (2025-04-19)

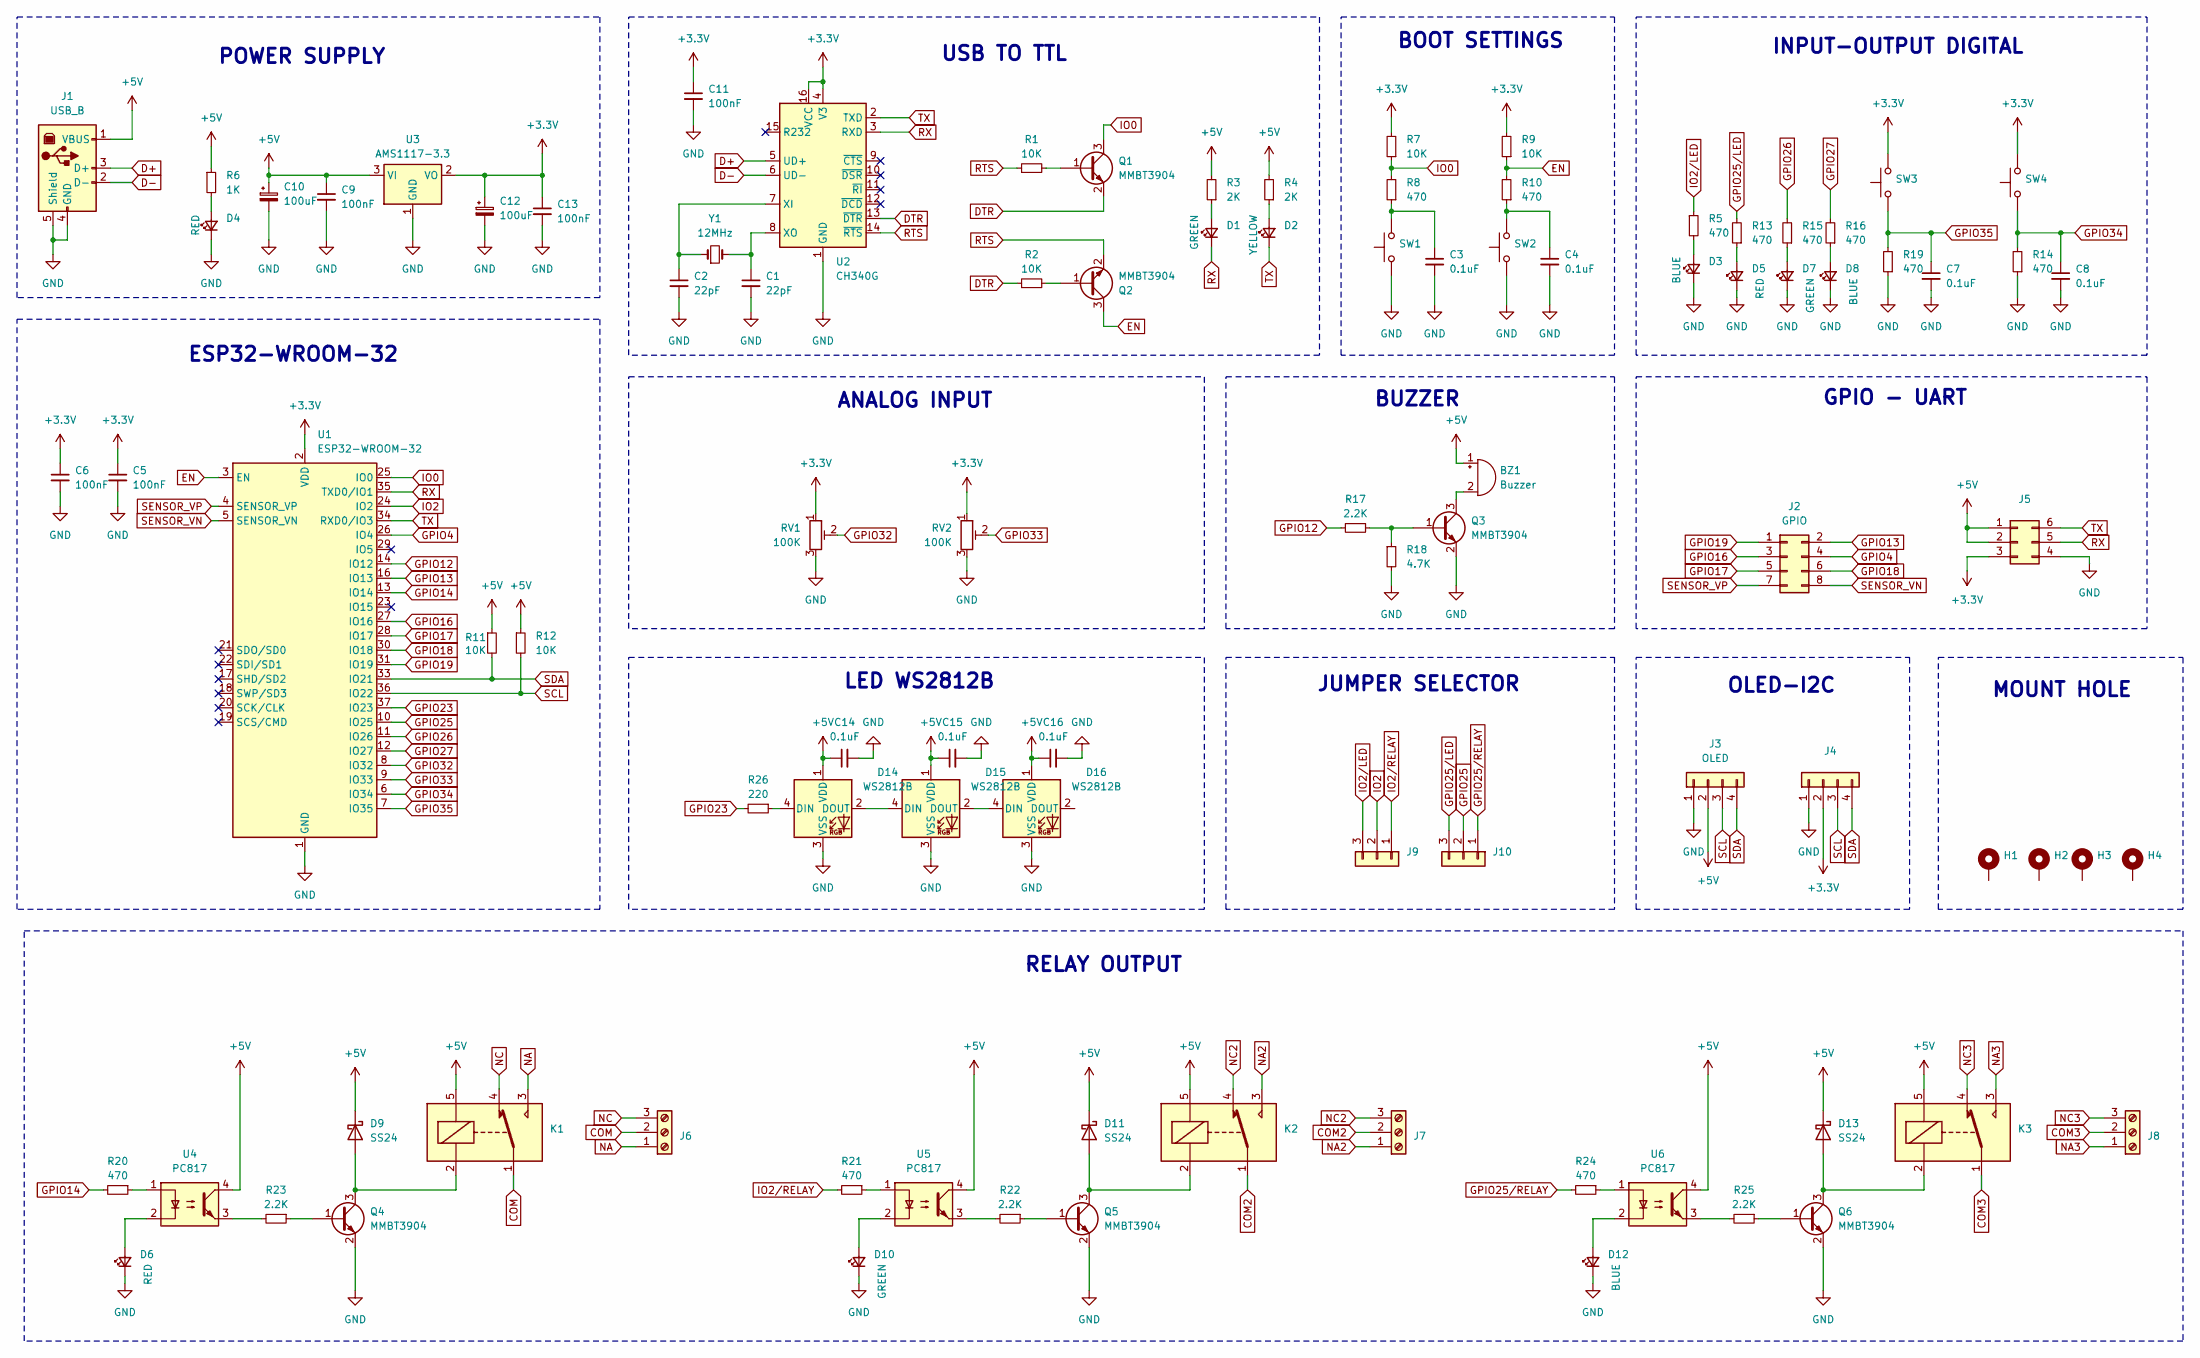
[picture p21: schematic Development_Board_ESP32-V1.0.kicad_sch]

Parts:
BZ1: Buzzer; Buzzer_12x9.5RM7.6
C1, C2: 22pF; C_1206_3216Metric_Pad1.33x1.80mm_HandSolder
C3, C4, C7, C8, C14, C15, C16: 0.1uF; C_1206_3216Metric_Pad1.33x1.80mm_HandSolder
C5, C6, C9, C11, C13: 100nF; C_1206_3216Metric_Pad1.33x1.80mm_HandSolder
C10, C12: 100uF; CP_Elec_5x5.4
D1, D7, D10: GREEN; LED_1210_3225Metric_Pad1.42x2.65mm_HandSolder
D2: YELLOW; LED_1210_3225Metric_Pad1.42x2.65mm_HandSolder
D3, D8, D12: BLUE; LED_1210_3225Metric_Pad1.42x2.65mm_HandSolder
D4, D5, D6: RED; LED_1210_3225Metric_Pad1.42x2.65mm_HandSolder
D9, D11, D13: SS24; D_SMA
D14, D15, D16: WS2812B; LED_WS2812B_PLCC4_5.0x5.0mm_P3.2mm
H1, H2, H3, H4: MountingHole_3.2mm_M3_Pad_Via
J1: USB_B; USB_B_Lumberg_2411_02_Horizontal
J2: GPIO; PinHeader_2x04_P2.54mm_Vertical
J3: OLED; PinSocket_1x04_P2.54mm_Vertical
J4: PinHeader_1x04_P2.54mm_Vertical
J5: PinHeader_2x03_P2.54mm_Vertical
J6, J7, J8: TerminalBlock_Phoenix_MKDS-1,5-3-5.08_1x03_P5.08mm_Horizont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
J9, J10: PinHeader_1x03_P2.54mm_Vertical
K1, K2, K3: Relay_SPDT_SANYOU_SRD_Series_Form_C
Q1, Q2, Q3, Q4, Q5, Q6: MMBT3904; SOT-23
R1, R2, R7, R9, R11, R12: 10K; R_1206_3216Metric_Pad1.30x1.75mm_HandSolder
R3, R4: 2K; R_1206_3216Metric_Pad1.30x1.75mm_HandSolder
R5, R8, R10, R13, R14, R15, R16, R19, R20, R21, R24: 470; R_1206_3216Metric_Pad1.30x1.75mm_HandSolder
R6: 1K; R_1206_3216Metric_Pad1.30x1.75mm_HandSolder
R17, R22, R23, R25: 2.2K; R_1206_3216Metric_Pad1.30x1.75mm_HandSolder
R18: 4.7K; R_1206_3216Metric_Pad1.30x1.75mm_HandSolder
R26: 220; R_1206_3216Metric_Pad1.30x1.75mm_HandSolder
RV1, RV2: 100K; Potentiometer_Bourns_3296W_Vertical
SW1, SW2: SW_Tactile_SPST_NO_Straight_CK_PTS636Sx25SMTRLFS
SW3, SW4: SW_PUSH_6mm
U1: ESP32-WROOM-32
U2: CH340G; SOIC-16_3.9x9.9mm_P1.27mm
U3: AMS1117-3.3; SOT-223-3_TabPin2
U4, U5, U6: PC817; DIP-4_W7.62mm
Y1: 12MHz; Crystal_HC49-4H_Vertical

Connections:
+3.3V: C5.1, C6.1, C11.1, C12.1, C13.1, J4.2, J5.3, R7.2, R9.2, RV1.1, RV2.1, SW3.2, SW4.2, U1.2 (VDD), U2.4 (V3), U2.16 (VCC), U3.2 (VO)
+5V: BZ1.1 (+), C9.1, C10.1, C14.1, C15.1, C16.1, D9.1 (K), D11.1 (K), D13.1 (K), D14.1 (VDD), D15.1 (VDD), D16.1 (VDD), J1.1 (VBUS), J3.2, J5.1, J5.2, K1.5, K2.5, K3.5, R3.2, R4.2, R6.1, R11.1, R12.1, U3.3 (VI), U4.4, U5.4, U6.4
COM: J6.2, K1.1
COM2: J7.2, K2.1
COM3: J8.2, K3.1
D+: J1.3 (D+), U2.5 (UD+)
D-: J1.2 (D-), U2.6 (UD-)
DTR: Q1.2 (E), R2.1, U2.13 (~DTR)
EN: Q2.3 (C), R9.1, R10.2, U1.3 (EN)
GND: C1.2, C2.2, C3.2, C4.2, C5.2, C6.2, C7.2, C8.2, C9.2, C10.2, C11.2, C12.2, C13.2, C14.2, C15.2, C16.2, D3.1 (K), D4.1 (K), D5.1 (K), D6.1 (K), D7.1 (K), D8.1 (K), D10.1 (K), D12.1 (K), D14.3 (VSS), D15.3 (VSS), D16.3 (VSS), J1.4 (GND), J1.5 (Shield), J3.1, J4.1, J5.4, Q3.2 (E), Q4.2 (E), Q5.2 (E), Q6.2 (E), R14.1, R18.2, R19.1, RV1.3, RV2.3, SW1.1, SW2.1, U1.1 (GND), U1.15 (GND), U1.38 (GND), U1.39 (GND), U2.1 (GND), U3.1 (GND)
GPIO4: J2.4, U1.26 (IO4)
GPIO12: R17.2, U1.14 (IO12)
GPIO13: J2.2, U1.16 (IO13)
GPIO14: R20.2, U1.13 (IO14)
GPIO16: J2.3, U1.27 (IO16)
GPIO17: J2.5, U1.28 (IO17)
GPIO18: J2.6, U1.30 (IO18)
GPIO19: J2.1, U1.31 (IO19)
GPIO23: R26.2, U1.37 (IO23)
GPIO25: J10.2, U1.10 (IO25)
GPIO25/LED: J10.3, R13.2
GPIO25/RELAY: J10.1, R24.2
GPIO26: R15.2, U1.11 (IO26)
GPIO27: R16.2, U1.12 (IO27)
GPIO32: RV1.2, U1.8 (IO32)
GPIO33: RV2.2, U1.9 (IO33)
GPIO34: C8.1, R14.2, SW4.1, U1.6 (IO34)
GPIO35: C7.1, R19.2, SW3.1, U1.7 (IO35)
IO0: Q1.3 (C), R7.1, R8.2, U1.25 (IO0)
IO2: J9.2, U1.24 (IO2)
IO2/LED: J9.3, R5.1
IO2/RELAY: J9.1, R21.2
NA: J6.1, K1.3
NA2: J7.1, K2.3
NA3: J8.1, K3.3
NC: J6.3, K1.4
NC2: J7.3, K2.4
NC3: J8.3, K3.4
unnamed: BZ1.2 (-), Q3.3 (C)
unnamed: C3.1, R8.1, SW1.2
unnamed: C4.1, R10.1, SW2.2
unnamed: D1.2 (A), R3.1
unnamed: D2.2 (A), R4.1
unnamed: D3.2 (A), R5.2
unnamed: D4.2 (A), R6.2
unnamed: D5.2 (A), R13.1
unnamed: D6.2 (A), U4.2
unnamed: D7.2 (A), R15.1
unnamed: D8.2 (A), R16.1
unnamed: D9.2 (A), K1.2, Q4.3 (C)
unnamed: D10.2 (A), U5.2
unnamed: D11.2 (A), K2.2, Q5.3 (C)
unnamed: D12.2 (A), U6.2
unnamed: D13.2 (A), K3.2, Q6.3 (C)
unnamed: D14.4 (DIN), R26.1
unnamed: D14.2 (DOUT), D15.4 (DIN)
unnamed: D15.2 (DOUT), D16.4 (DIN)
unnamed: Q1.1 (B), R1.2
unnamed: Q2.1 (B), R2.2
unnamed: Q3.1 (B), R17.1, R18.1
unnamed: Q4.1 (B), R23.1
unnamed: Q5.1 (B), R22.1
unnamed: Q6.1 (B), R25.1
unnamed: R20.1, U4.1
unnamed: R21.1, U5.1
unnamed: R22.2, U5.3
unnamed: R23.2, U4.3
unnamed: R24.1, U6.1
unnamed: R25.2, U6.3
unnamed: C2.1, U2.7 (XI), Y1.1
unnamed: C1.1, U2.8 (XO), Y1.2
RTS: Q2.2 (E), R1.1, U2.14 (~RTS)
RX: D1.1 (K), J5.5, U1.35 (TXD0/IO1), U2.3 (RXD)
SCL: J3.3, J4.3, R12.2, U1.36 (IO22)
SDA: J3.4, J4.4, R11.2, U1.33 (IO21)
SENSOR_VN: J2.8, U1.5 (SENSOR_VN)
SENSOR_VP: J2.7, U1.4 (SENSOR_VP)
TX: D2.1 (K), J5.6, U1.34 (RXD0/IO3), U2.2 (TXD)

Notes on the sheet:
ANALOG INPUT
BUZZER
ESP32-WROOM-32
POWER SUPPLY
LED WS2812B
MOUNT HOLE
INPUT-OUTPUT DIGITAL
BOOT SETTINGS
RELAY OUTPUT
JUMPER SELECTOR
GPIO - UART
OLED-I2C
USB TO TTL

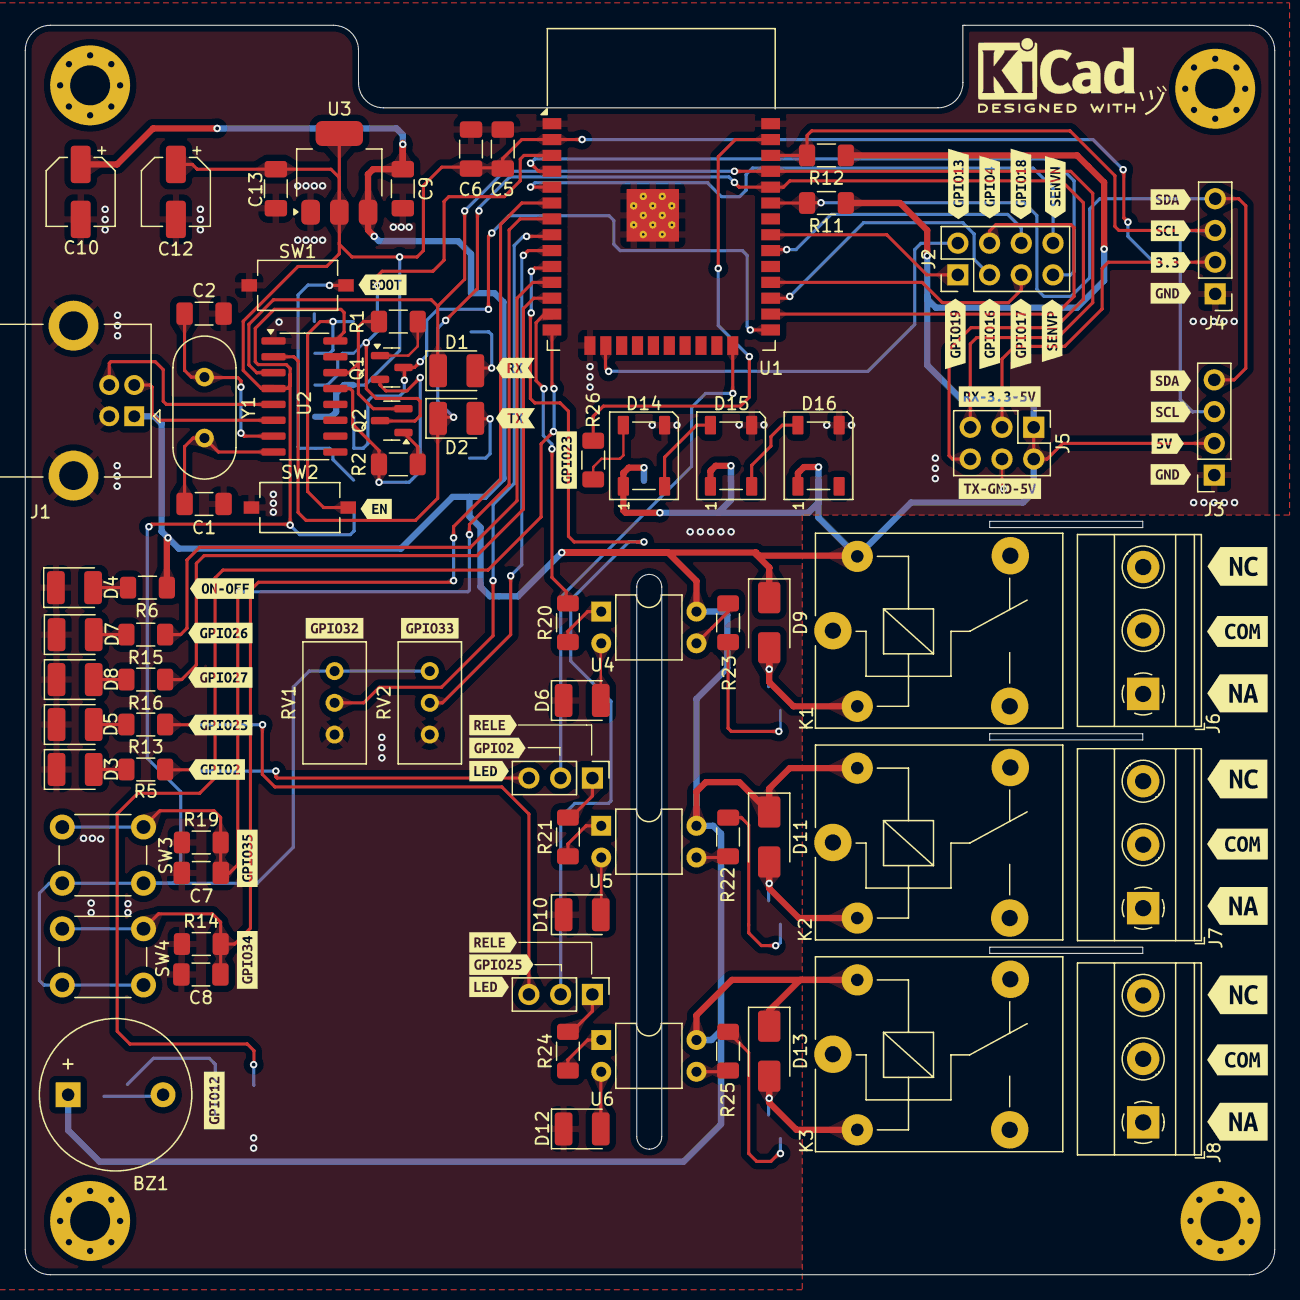
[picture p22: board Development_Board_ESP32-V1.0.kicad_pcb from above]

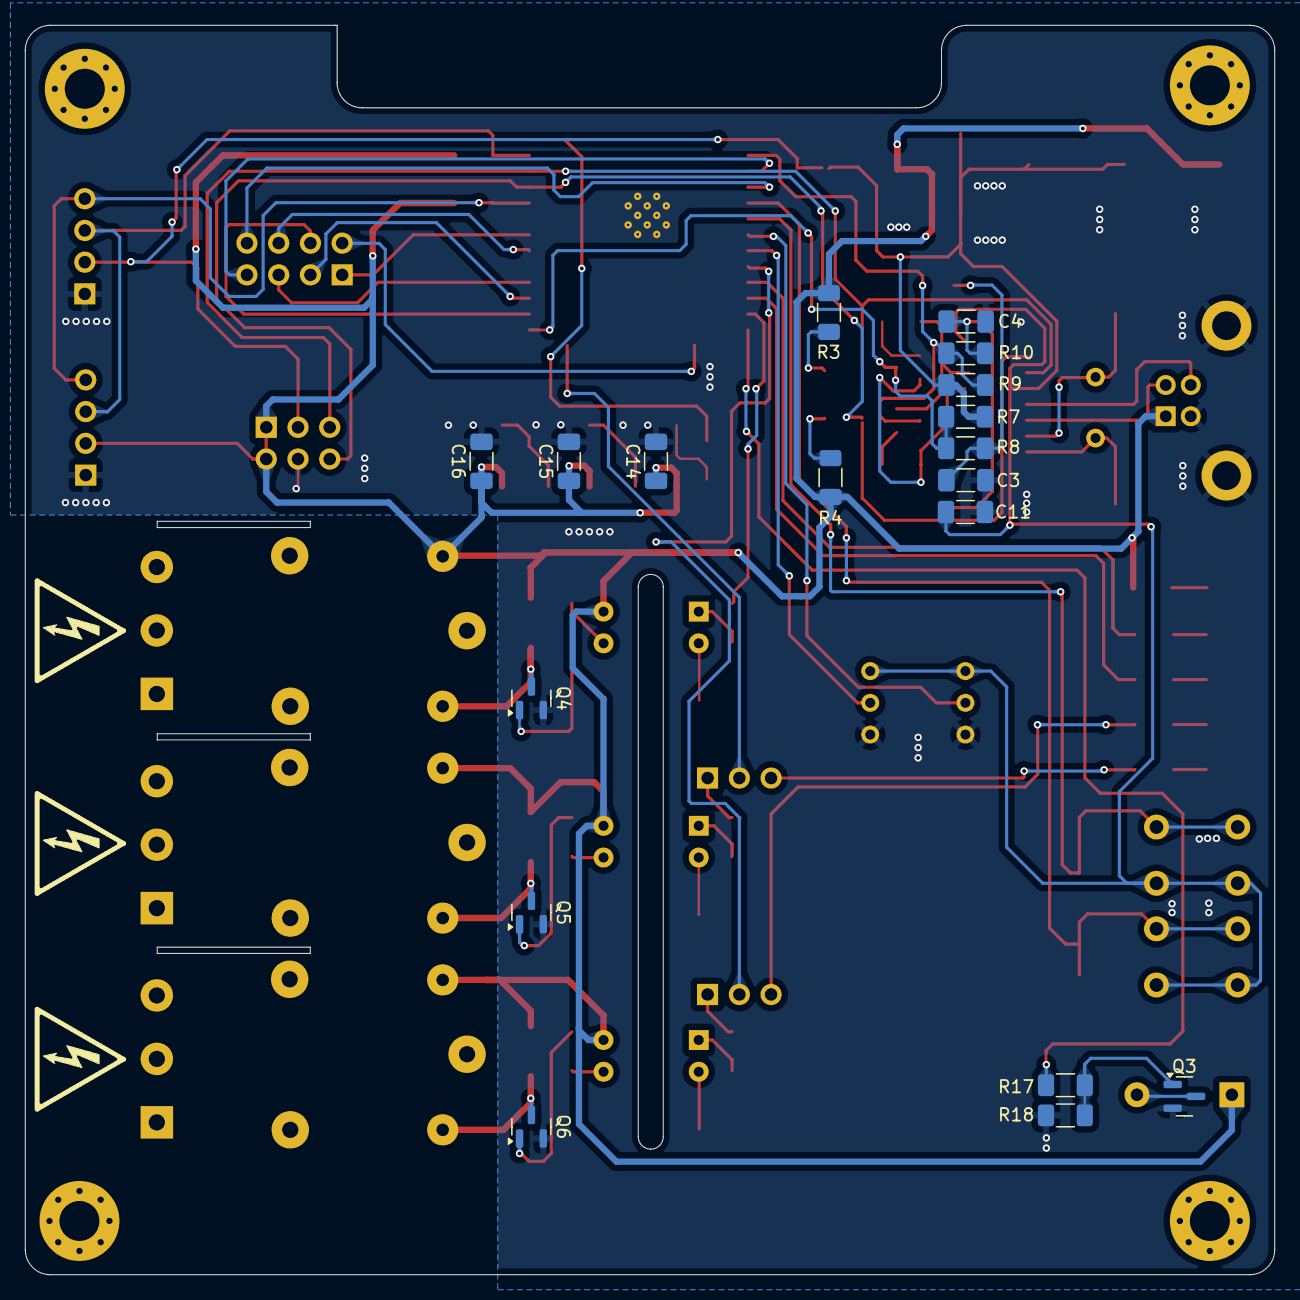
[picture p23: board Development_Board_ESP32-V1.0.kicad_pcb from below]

Board: 2 copper layers, 100.0 x 100.0 mm, 143 parts (18 on the bottom side), 78 nets.

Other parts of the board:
kibuzzard-67C7CC9C: G***; kibuzzard-67C7CC9C
kibuzzard-67C7CCC6: G***; kibuzzard-67C7CCC6
kibuzzard-67C7CCDB: G***; kibuzzard-67C7CCDB
kibuzzard-67C7CD00: G***; kibuzzard-67C7CD00
kibuzzard-67C7CD0D: G***; kibuzzard-67C7CD0D
kibuzzard-67C7CD05: G***; kibuzzard-67C7CD05
kibuzzard-67C7CEE3, kibuzzard-67C7CEE3#2: G***; kibuzzard-67C7CEE3
kibuzzard-67C7CEF2, kibuzzard-67C7CEF2#2: G***; kibuzzard-67C7CEF2
kibuzzard-67C7CF27, kibuzzard-67C7CF27#2: G***; kibuzzard-67C7CF27
kibuzzard-67C7CF34: G***; kibuzzard-67C7CF34
kibuzzard-67C7CF78: G***; kibuzzard-67C7CF78
kibuzzard-67C7CFC3, kibuzzard-67C7CFC3#2: G***; kibuzzard-67C7CFC3
kibuzzard-67C7D0D9, kibuzzard-67C7D0D9#2, kibuzzard-67C7D0D9#3: G***; kibuzzard-67C7D0D9
kibuzzard-67C7D0EE, kibuzzard-67C7D0EE#2, kibuzzard-67C7D0EE#3: G***; kibuzzard-67C7D0EE
kibuzzard-67C7D02E, kibuzzard-67C7D02E#2: G***; kibuzzard-67C7D02E
kibuzzard-67C7D15A: G***; kibuzzard-67C7D15A
kibuzzard-67C7D26A: G***; kibuzzard-67C7D26A
kibuzzard-67C7D134: G***; kibuzzard-67C7D134
kibuzzard-67C7D148: G***; kibuzzard-67C7D148
kibuzzard-67C7D258: G***; kibuzzard-67C7D258
kibuzzard-67C8441C: G***; kibuzzard-67C8441C
kibuzzard-67C8442B: G***; kibuzzard-67C8442B
kibuzzard-67C84437: G***; kibuzzard-67C84437
kibuzzard-67C84440: G***; kibuzzard-67C84440
kibuzzard-67CB0A01: G***; kibuzzard-67CB0A01
kibuzzard-67CB0A75: G***; kibuzzard-67CB0A75
kibuzzard-67CB0A81: G***; kibuzzard-67CB0A81
kibuzzard-67CB0AA4: G***; kibuzzard-67CB0AA4
kibuzzard-67CB0AB6: G***; kibuzzard-67CB0AB6
kibuzzard-67CB0AEE: G***; kibuzzard-67CB0AEE
kibuzzard-67CB08BA: G***; kibuzzard-67CB08BA
kibuzzard-67CB08E7: G***; kibuzzard-67CB08E7
kibuzzard-67CB21E1: G***; kibuzzard-67CB21E1
kibuzzard-67CB32EA: G***; kibuzzard-67CB32EA
kibuzzard-67CB089A: G***; kibuzzard-67CB089A
kibuzzard-67CB0885: G***; kibuzzard-67CB0885
kibuzzard-67CB0907: G***; kibuzzard-67CB0907
kibuzzard-67CB0943: G***; kibuzzard-67CB0943
kibuzzard-67CB3300: G***; kibuzzard-67CB3300

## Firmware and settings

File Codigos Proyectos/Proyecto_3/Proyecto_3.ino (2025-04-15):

#include "RMaker.h"
#include "WiFi.h"
#include "WiFiProv.h"

// Nombre del dispositivo y credenciales BLE
const char *service_name = "MI_CASA_ESP32";
const char *pop = "12345678";

// Nombres personalizados para los dispositivos (focos)
char deviceName_1[] = "Foco Sala";
char deviceName_2[] = "Foco Comedor";
char deviceName_3[] = "Foco Cuarto";

// Pines de salida conectados a los relés
static uint8_t RelayPin1 = 25;
static uint8_t RelayPin2 = 2;
static uint8_t RelayPin3 = 14;

static uint8_t wifiLed = 26;
static uint8_t gpio_reset = 0;

// Estado de los relés (coincide con el estado real del foco)
bool toggleState_1 = LOW; // LOW = apagado
bool toggleState_2 = LOW;
bool toggleState_3 = LOW;

// Definición de los dispositivos en RainMaker
static Switch my_hall_Light(deviceName_1, &RelayPin1);
static Switch my_Kitchen_Light(deviceName_2, &RelayPin2);
static Switch my_bedroom_Light(deviceName_3, &RelayPin3);

// Eventos del sistema para provisión BLE
void sysProvEvent(arduino_event_t *sys_event)
{
  switch (sys_event->event_id)
  {
  case ARDUINO_EVENT_PROV_START:
    Serial.printf("\nProvisioning Started with name \"%s\" and PoP \"%s\"\n", service_name, pop);
    printQR(service_name, pop, "ble");
    break;
  case ARDUINO_EVENT_WIFI_STA_CONNECTED:
    Serial.printf("\nConnected to Wi-Fi!\n");
    digitalWrite(wifiLed, true);
    break;
  }
}

// Callback de escritura (encender/apagar luces desde RainMaker)
void write_callback(Device *device, Param *param, const param_val_t val, void *priv_data, write_ctx_t *ctx)
{
  const char *device_name = device->getDeviceName();
  const char *param_name = param->getParamName();

  if (strcmp(param_name, "Power") == 0)
  {
    bool newState = val.val.b;

    if (strcmp(device_name, deviceName_1) == 0)
    {
      toggleState_1 = newState;
      digitalWrite(RelayPin1, toggleState_1);  // Corregido: ahora HIGH enciende el foco
    }
    else if (strcmp(device_name, deviceName_2) == 0)
    {
      toggleState_2 = newState;
      digitalWrite(RelayPin2, toggleState_2);
    }
    else if (strcmp(device_name, deviceName_3) == 0)
    {
      toggleState_3 = newState;
      digitalWrite(RelayPin3, toggleState_3);
    }

    param->updateAndReport(val);
    Serial.printf("Dispositivo: %s -> Estado: %s\n", device_name, newState ? "ENCENDIDO" : "APAGADO");
  }
}

void init_GPIO()
{
  pinMode(RelayPin1, OUTPUT);
  pinMode(RelayPin2, OUTPUT);
  pinMode(RelayPin3, OUTPUT);
  pinMode(wifiLed, OUTPUT);
  pinMode(gpio_reset, INPUT);

  // Inicializar relés en estado apagado (LOW)
  digitalWrite(RelayPin1, toggleState_1);
  digitalWrite(RelayPin2, toggleState_2);
  digitalWrite(RelayPin3, toggleState_3);
  digitalWrite(wifiLed, LOW);
}

void init_RainMaker()
{
  uint32_t chipId = 0;
  Node my_node = RMaker.initNode("Rainmaker_Home_Lights");

  my_hall_Light.addCb(write_callback);
  my_Kitchen_Light.addCb(write_callback);
  my_bedroom_Light.addCb(write_callback);

  my_node.addDevice(my_hall_Light);
  my_node.addDevice(my_Kitchen_Light);
  my_node.addDevice(my_bedroom_Light);

  RMaker.enableOTA(OTA_USING_PARAMS);
  RMaker.enableTZService();
  RMaker.enableSchedule();

  for (int i = 0; i < 17; i += 8)
  {
    chipId |= ((ESP.getEfuseMac() >> (40 - i)) & 0xff) << i;
  }

  Serial.printf("\nChip ID: %d | Service Name: %s\n", chipId, service_name);
  RMaker.start();

  WiFi.onEvent(sysProvEvent);

  WiFiProv.beginProvision(NETWORK_PROV_SCHEME_BLE, NETWORK_PROV_SCHEME_HANDLER_FREE_BTDM, NETWORK_PROV_SECURITY_1, pop, service_name);

  // Reportar estado inicial como apagado
  my_hall_Light.updateAndReportParam(ESP_RMAKER_DEF_POWER_NAME, false);
  my_Kitchen_Light.updateAndReportParam(ESP_RMAKER_DEF_POWER_NAME, false);
  my_bedroom_Light.updateAndReportParam(ESP_RMAKER_DEF_POWER_NAME, false);
}

void setup()
{
  Serial.begin(115200);
  Serial.println("Iniciando sistema solo control por voz...");
  init_GPIO();
  init_RainMaker();
}

void loop()
{
  if (digitalRead(gpio_reset) == LOW)
  {
    delay(100);
    int startTime = millis();
    while (digitalRead(gpio_reset) == LOW)
      delay(50);
    int duration = millis() - startTime;

    if (duration > 10000)
    {
      Serial.println("Factory reset...");
      RMakerFactoryReset(2);
    }
    else if (duration > 3000)
    {
      Serial.println("WiFi reset...");
      RMakerWiFiReset(2);
    }
  }

  digitalWrite(wifiLed, WiFi.status() == WL_CONNECTED);
  delay(100);
}

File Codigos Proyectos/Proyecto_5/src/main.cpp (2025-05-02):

#include <Arduino.h>
#include "HC_SR04.h"
#include "PantallitaXD.h"
HC_SR04 sensor1(4, 18);

int distancia_sensada = 3; //CM
PantallitaXD pantalla1;
void setup()
{
  Serial.begin(115200);
  pantalla1.init();
  pinMode(2, OUTPUT);

}

void loop()
{
  // Serial.print("Distancia en Cm: ");
  // Serial.println(sensor1.getDistanceCM());
  // Serial.print("Distancia en Inch: ");
  // Serial.println(sensor1.getDistanceInch());
  // Serial.print("Distancia en M: ");
  // Serial.println(sensor1.getDistanceM());
  // Serial.print("Distancia en MM: ");
  // Serial.println(sensor1.getDistanceMM());
  // Serial.println("-------------------------------------------------");
  pantalla1.printHC_SR04(sensor1.getDistanceMM(), sensor1.getDistanceCM(), sensor1.getDistanceM(), sensor1.getDistanceInch());

  if(sensor1.getDistanceCM() < distancia_sensada)
  {
    Serial.println("El objeto está muy cerca");
    digitalWrite(2, HIGH);
  }
  else
  {
    Serial.println("El objeto está lejos");
    digitalWrite(2, LOW);
  }
  delay(500);
}

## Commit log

2025-03-18 Agregando Proyecto KiCad
    [Development_Board_ESP32-V1.0.kicad_pcb, Development_Board_ESP32-V1.0.kicad_pcb_bom.csv, Development_Board_ESP32-V1.0.kicad_pcb_positions.csv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]
2025-03-23 Libreria PWM
2025-04-19 Subiendo todo por si cambio
    [Development_Board_ESP32-V1.0.kicad_pcb, Development_Board_ESP32-V1.0.kicad_sch, bom.csv]
2025-04-29 Agregando el Menu
2025-04-29 Arreglando el Temario
2025-04-29 Subiendo Intro y Frames
2025-04-29 Subiendo Frames
2025-04-29 Arreglando los frames
2025-04-30 Arreglando los frames2
2025-04-30 Agregando ultimas imagenes del pcb
2025-04-30 Agregando el PCB - Esquematico
2025-08-04 Arreglando Voltaje en esquematico
    [Development_Board_ESP32-V1.0.kicad_sch]
